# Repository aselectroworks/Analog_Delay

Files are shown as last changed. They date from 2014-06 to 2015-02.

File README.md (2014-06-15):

Analog_Delay
============

Multiple function BBD Analog Delay assisted by Digital Domain. 

### Features
* Max. 1000 ms delay by 4 BBDs
* Stereo In/Out
* Monaural In/Stereo Out(ping-pong or fx+dryout)
* Tap tempo function assisted by digital domain 
* Delay effect remain or bypass selectable when fx function off
* LCD display

### Design Tools
* [KiCAD](http://www.kicad-pcb.org/)
* [atmel studio 6](http://www.atmel.com/tools/ATMELSTUDIO.aspx)

### Download
You can download this project in either [zip](https://github.com/aselectroworks/Analog_Delay/zipball/master) or [tar](https://github.com/aselectroworks/Analog_Delay/tarball/master) formats. 
You can also clone this project with [git](http://git-scm.com/) by runninng: 
```
$ git clone git://github.com/aselectroworks/Analog_Delay
```

### License
GPL v3

### Contact
atsushi.sasaki@aselectroworks.com

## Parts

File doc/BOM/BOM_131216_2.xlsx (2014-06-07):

ID | Parts Ref. Number | Package | pcs | Value | Toralance | Voltage | Type | Parts Name | Manufacturer | Smart-Prototyping Materials | Shop URL
1 | C631,C609,C635,C613,C628,C606,C213,C206,C218,C214,C321,C205,C212,C615,C616,C617,C620,C621,C622,C629,C636,C607,C230,C223,C301,C231,C224,C614,C314,C309,C308,C322,C644,C638,C641,C501,C502 | C0402 | 37 | 100n | ±10% | 16V | X7R | GRM155R71C104KA88D | - | Yes | -
2 | R620,R606,R221,R206 | R0402 | 4 | 47k | ±5% | - | - | - | - | Yes | -
3 | R602,R616,R225,R219,R204,R210 | R0603 | 6 | 3.3k | ±5% | - | - | - | - | Yes | -
4 | R611,R626,R229,R214 | R0603 | 4 | 1.5k | ±5% | - | - | - | - | Yes | -
5 | R603,R608,R622,R617 | R0603 | 4 | 2.7k | ±5% | - | - | - | - | Yes | -
6 | R612,R627 | R0603 | 2 | 1.2k | ±5% | - | - | - | - | Yes | -
7 | R609,R623 | R0603 | 2 | 2.2k | ±5% | - | - | - | - | Yes | -
8 | C610,C632,C209,C227 | C0603 | 4 | 22n | ±10% | 25V | X7R | GRM188R71E223KA01D | - | Yes | -
9 | C604,C626,C624,C602,C202,C627,C221,C220,C222,C203,C204,C605 | C0603 | 12 | 10n | ±10% | 25V | X7R | GRM188R71E103KA01D | - | Yes | -
10 | C611,C633,C210,C228 | C0603 | 4 | 33n | ±10% | 16V | X7R | GRM188R71C333KA01D | - | Yes | -
11 | U601,U606,U205,U204,U607,U602,U202,U201 | DMP8 | 8 | NJM4558M | - | - | - | NJM4558M | JRC | - | http://hongkong01.rs-online.com/web/p/operational-amplifiers/7405581/
12 | D401 | UMD2 | 1 | 1SS355VMTE-17 | - | - | - | 1SS355VMTE-17 | Rohm | - | http://www.digikey.hk/product-detail/en/1SS355VMTE-17/1SS355VMTE-17CT-ND/3443692
13 | U403 | DPAK | 1 | MC79M05CDTG | - | - | - | MC79M05CDTG | ON Semiconductor | - | http://www.digikey.hk/product-detail/en/MC79M05CDTG/MC79M05CDTGOS-ND/1481613
14 | U401 | TO-252-3 | 1 | NJM78M05DL1A | - | - | - | NJM78M05DL1A | JRC | - | http://hongkong02.rs-online.com/web/p/linear-voltage-regulators/7139543/?searchTerm=NJM78M05DL1A
15 | U402 | S8 | 1 | LTC1144CS8 | - | - | - | LTC1144CS8 | Linear Technology | - | http://www.digikey.hk/product-detail/en/LTC1144CS8%23PBF/LTC1144CS8%23PBF-ND/889942
16 | R224,R228,R218,R209,R203,R213 | R0603 | 6 | 3.9k | ±5% | - | - | - | - | Yes | -
17 | R215,R230 | R0603 | 2 | 1M | ±5% | - | - | - | - | Yes | -
18 | R621,R629,R615,R332,R316,R333,R601,R607,R614,R630,R222,R205,R207,R220,R334,R632 | R0603 | 16 | 47k | ±5% | - | - | - | - | Yes | -
19 | R619,R605 | R0603 | 2 | 6.8k | ±5% | - | - | - | - | Yes | -
20 | R402,R401 | R0603 | 2 | 0 | ±5% | - | - | - | - | Yes | -
21 | R604,R618 | R0603 | 2 | 1k | ±5% | - | - | - | - | Yes | -
22 | R613,R610,R624,R628 | R0603 | 4 | 820 | ±5% | - | - | - | - | Yes | -
23 | R625,R631 | R0603 | 2 | 33 | ±5% | - | - | - | - | Yes | -
24 | R226,R211 | R0603 | 2 | 5.1k | ±5% | - | - | - | - | Yes | -
25 | R217,R202,R201,R208,R223,R216,R232,R231 | R0603 | 8 | 5.6k | ±5% | - | - | - | - | Yes | -
26 | R212,R227 | R0603 | 2 | 4.7k | ±5% | - | - | - | - | Yes | -
27 | J401 | MJ-179SMT | 1 | MJ-179SMT | - | - | - | MJ-179SMT | - | - | http://sg.element14.com/multicomp/mj-179smt/chassis-socket-psu-smt-2mm-pin/dp/1737262
28 | C403,C404,C406,C401,C402,C407,C405,C216,C217,C619,C618,C639,C642,C637,C640 | C0805 | 15 | 10u | ±10% | 10V | X5R | GRM21BR61A106KE19L | - | Yes | -
29 | C208,C623,C226,C601 | C0603 | 4 | 15n | ±10% | 25V | X7R | GRM188R71E153KA01D | - | Yes | -
30 | C634,C612 | C0603 | 2 | 100n | ±10% | 16V | X7R | GRM188R71C104KA01D | - | Yes | -
31 | C630,C625,C603,C608 | C0603 | 4 | 3.3n | ±10% | 50V | X7R | GRM188R71H332KA01D | - | Yes | -
32 | C201,C219 | C0603 | 2 | 1.2n | ±10% | 50V | X7R | GRM188R71H122KA01D | - | Yes | -
33 | C304,C317,C207,C225,C646,C234,C233,C320,C307 | C0603 | 9 | 2.2u | ±10% | 6.3V | X5R | GRM188R60J225KE19D | - | Yes | -
34 | C229,C211 | C0603 | 2 | 82n | ±10% | 16V | X7R | GRM188R71C823KA01D | - | Yes | -
35 | J602,J601,J202,J201 | ACJS-MHDRM | 4 | ACJS-MHDRM | - | - | - | ACJS-MHDRM | Amphenol | - | http://hk.mouser.com/ProductDetail/Amphenol/ACJS-MHDRM/
36 | SW501,SW502 | 8Y10 | 2 | 8Y1021 | - | - | - | 8Y1021 | Fujisoku | - | http://hongkong01.rs-online.com/web/p/push-button-switches/0223430/?searchTerm=8Y1021
37 | C313,C311,C306,C324,C319,C310,C303,C323,C316,C312,C326,C325 | C0402 | 12 | 1u | ±10% | 10V | X5R | GRM155R61A105KE15D | - | Yes | -
38 | C318,C315,C302,C305 | C0402 | 4 | 10n | ±10% | 50V | X7R | GRM155R71H103KA88D | - | Yes | -
39 | C232,C215 | C0402 | 2 | 1n | ±10% | 50V | X7R | GRM155R71H102KA01D | - | Yes | -
40 | R328,R329,R312,R313 | R0402 | 4 | 100k | ±5% | - | - | - | - | Yes | -
41 | R304,R321,R322,R323,R320,R307,R306,R305 | R0402 | 8 | 0 | ±5% | - | - | - | - | Yes | -
42 | R325,R324,R308,R309 | R0402 | 4 | 12k | ±5% | - | - | - | - | Yes | -
43 | R318,R302,R303,R319 | R0402 | 4 | Don't Source | - | - | - | - | - | - | -
44 | R317,R301 | R0402 | 2 | 5.6k | ±5% | - | - | - | - | Yes | -
45 | R327,R330,R326,R331,R310,R314,R315,R311 | R0402 | 8 | 4.7k | ±5% | - | - | - | - | Yes | -
46 | U608 | RU-16 | 1 | AD5282BRUZ200 | - | - | - | AD5282BRUZ200 | Analog Devices | - | http://www.digikey.hk/product-detail/en/AD5282BRUZ200/AD5282BRUZ200-ND/936629
47 | R639,R633,R634 | R0402 | 3 | 10k | ±5% | - | - | - | - | Yes | -
48 | R636,R635,R637,R638,R501,R502,R640 | R0402 | 7 | 100 | ±5% | - | - | - | - | Yes | -
49 | X601 | DNP | 1 | Don't Source | - | - | - | - | - | - | -
50 | P601 | DNP | 1 | Don't Source | - | - | - | - | - | - | -
51 | C643,C645 | C0603 | 2 | 1u | ±10% | 10V | X5R | GRM188R61A105KA61D | - | Yes | -
52 | C647 | C0402 | 1 | 1n | ±10% | 50V | X7R | GRM155R71H102KA01D | - | Yes | -
53 | C649,C648 | C0402 | 2 | 22p | ±5% | 50V | C0G | GRM1555C1H220JZ01D | - | Yes | -
54 | IC601 | 20S2 | 1 | ATTINY861A-S | - | - | - | ATTINY861A-S | Atmel | - | http://www.digikey.hk/product-detail/en/ATTINY861A-SUR/ATTINY861A-SURCT-ND/2774370
55 | CON601 | 06FMN-BMTTN-A-TF | 1 | 06FMN-BMTTN-A-TF | - | - | - | 06FMN-BMTTN-A-TF | JST | - | http://www.digikey.hk/product-detail/en/06FMN-BMTTN-A-TF(LF)(SN)/455-1922-1-ND/1634946
56 | U604 | RU-24 | 1 | AD5263BRU200 | - | - | - | AD5263BRU200 | Analog Devices | - | http://www.digikey.hk/product-search/en?WT.z_header=search_go&lang=en&site=hk&formaction=on&x=0&y=0
57 | U203 | RM-10 | 1 | ADG621BRMZ | - | - | - | ADG621BRMZ | Analog Devices | - | http://www.digikey.hk/product-detail/en/ADG621BRMZ/ADG621BRMZ-ND/997745
58 | U605,U603,U310,U305 | RM-8 | 4 | ADG619BRMZ | - | - | - | ADG619BRMZ | Analog Devices | - | http://www.digikey.hk/product-detail/en/ADG619BRMZ/ADG619BRMZ-ND/820101
59 | U306,U307,U302,U301 | DNP | 4 | Don't Source | - | - | - | - | - | - | -
60 | U308,U309,U304,U303 | DNP | 4 | Don't Source | - | - | - | - | - | - | -

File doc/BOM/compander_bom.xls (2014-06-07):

Id | Designator | Package | Quantity | Designation | Supplier and ref
1 | D105,D104,D101,D102,D103 | UMD2 | 5 | 1SS355VMTE-17 | http://www.rohm.com/web/global/products/-/product/1SS355VM
2 | U101 | SOIC-16_WB | 1 | SA571DG | http://www.onsemi.jp/PowerSolutions/product.do?id=SA571
3 | P101,P102 | S6B-PH-K-S | 2 | OPEN | DON'T SOURCE
4 | RV101,RV102 | RV2 | 2 | OPEN | DON'T SOURCE
5 | R108,R102,R117,R101,R107 | r_1608 | 5 | 0 | 0603size(1.6mm x 0.8mm)
6 | R110,R109 | r_1608 | 2 | OPEN | DON'T SOURCE
7 | R105,R106,R103,R104 | r_1608 | 4 | 22k | 0603size(1.6mm x 0.8mm), tolerance: 5%, in your web shop
8 | R112,R114,R111,R113 | r_1608 | 4 | 10k | 0603size(1.6mm x 0.8mm), tolerance: 5%, in your web shop
9 | R116,R115 | r_1608 | 2 | 5.6k | 0603size(1.6mm x 0.8mm), tolerance: 5%, in your web shop
10 | C122,C115,C116 | c_2012 | 3 | GRM21BR61A106KE19L | 10uF±10% 10V X5R, in your web shop
11 | C104,C119,C101,C102,C117,C103,C105,C107,C109,C110,C108,C120,C118,C106 | c_1608 | 14 | GRM188R60J225KE19D | 2.2uF±10% 6.3V X5R, in your web shop
12 | C113,C114 | c_1608 | 2 | GRM1885C1H201JA01D | 200pF±5% 50V C0G, in your web shop
13 | C121 | c_1608 | 1 | GRM188R71C104KA01D | 100nF±10% 16V X7R, in your web shop
14 | C111,C112 | c_1608 | 2 | GRM188R71C224KA01D | 220nF±10% 16V X7R, in your web shop

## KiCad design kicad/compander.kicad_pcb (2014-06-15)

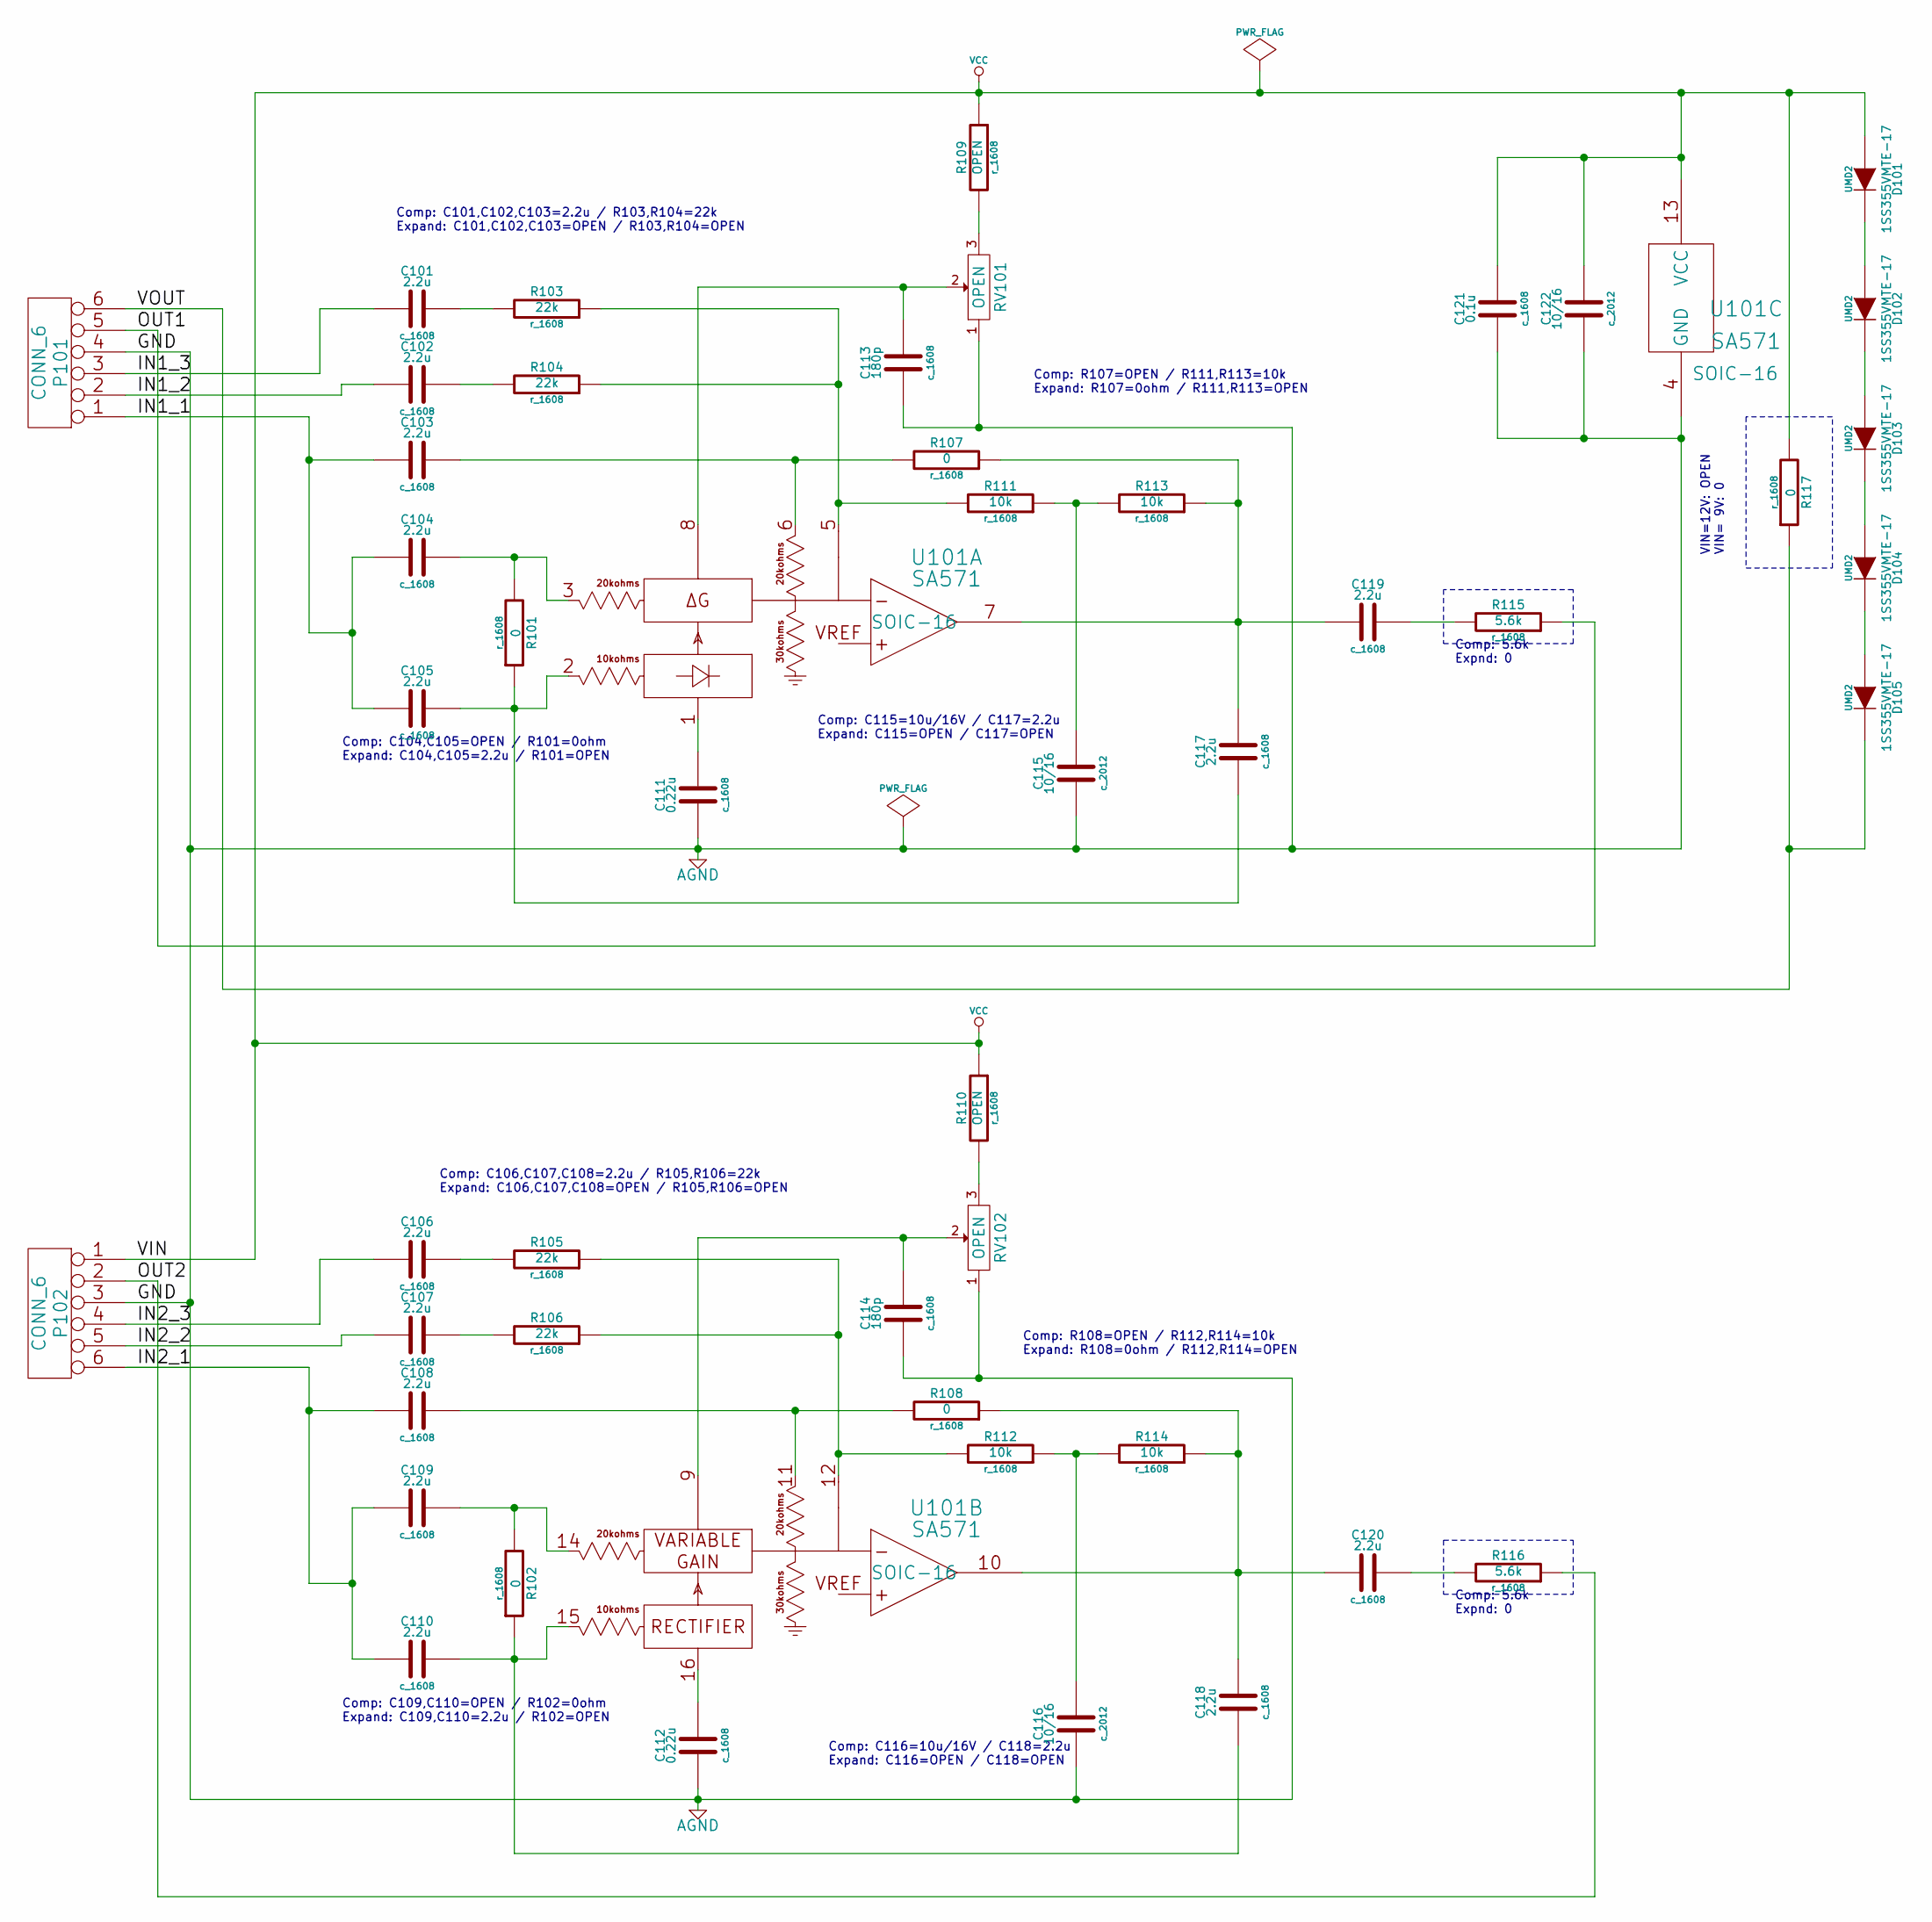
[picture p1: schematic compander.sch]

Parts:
C101, C102, C103, C104, C105, C106, C107, C108, C109, C110, C117, C118, C119, C120: 2.2u; c_1608
C111, C112: 0.22u; c_1608
C113, C114: 180p; c_1608
C115, C116, C122: 10/16; c_2012
C121: 0.1u; c_1608
D101, D102, D103, D104, D105: 1SS355VMTE-17; UMD2
P101, P102: CONN_6
R101, R102, R107, R108, R117: 0; r_1608
R103, R104, R105, R106: 22k; r_1608
R109, R110: OPEN; r_1608
R111, R112, R113, R114: 10k; r_1608
R115, R116: 5.6k; r_1608
RV101, RV102: OPEN
U101: SA571; SOIC-16

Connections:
/IN1_1: C103.1, C104.1, C105.1, P101.1
/IN1_2: C102.1, P101.2
/IN1_3: C101.1, P101.3
/IN2_1: C108.1, C109.1, C110.1, P102.6
/IN2_2: C107.1, P102.5
/IN2_3: C106.1, P102.4
/OUT1: P101.5, R115.1
/OUT2: P102.2, R116.1
/VOUT: D105.2 (K), P101.6, R117.1
AGND: C111.1, C112.1, C113.1, C114.1, C115.1, C116.1, C121.1, C122.1, P101.4, P102.3, RV101.1, RV102.1, U101.4 (GND)
unnamed: C114.2, RV102.2, U101.9 (THD_TRIM_2)
unnamed: R110.2, RV102.3
unnamed: C104.2, R101.2, U101.3 (DG_CELL_IN_1)
unnamed: R105.1, R106.1, R112.2, U101.12 (INV._IN_2)
unnamed: C107.2, R106.2
unnamed: C106.2, R105.2
unnamed: C120.2, R116.2
unnamed: C115.2, R111.1, R113.2
unnamed: R103.1, R104.1, R111.2, U101.5 (INV._IN_1)
unnamed: C102.2, R104.2
unnamed: C101.2, R103.2
unnamed: C119.2, R115.2
unnamed: C105.2, C117.1, R101.1, U101.2 (RECT_IN_1)
unnamed: C116.2, R112.1, R114.2
unnamed: C111.2, U101.1 (RECT_CAP_1)
unnamed: C103.2, R107.2, U101.6 (RES._R3_1)
unnamed: C117.2, C119.1, R107.1, R113.1, U101.7 (OUTPUT_1)
unnamed: D101.2 (K), D102.1 (A)
unnamed: D104.2 (K), D105.1 (A)
unnamed: D103.2 (K), D104.1 (A)
unnamed: D102.2 (K), D103.1 (A)
unnamed: C112.2, U101.16 (RECT_CAP_2)
unnamed: C108.2, R108.2, U101.11 (RES._R3_2)
unnamed: C118.2, C120.1, R108.1, R114.1, U101.10 (OUTPUT_2)
unnamed: C110.2, C118.1, R102.1, U101.15 (RECT_IN_2)
unnamed: C109.2, R102.2, U101.14 (DG_CELL_IN_2)
unnamed: C113.2, RV101.2, U101.8 (THD_TRIM_1)
unnamed: R109.2, RV101.3
VCC: C121.2, C122.2, D101.1 (A), P102.1, R109.1, R110.1, R117.2, U101.13 (VCC)

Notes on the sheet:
Comp: 5.6k Expnd: 0
VIN=12V: OPEN VIN= 9V: 0
Comp: C104,C105=OPEN / R101=0ohm Expand: C104,C105=2.2u / R101=OPEN
Comp: C109,C110=OPEN / R102=0ohm Expand: C109,C110=2.2u / R102=OPEN
Comp: C106,C107,C108=2.2u / R105,R106=22k Expand: C106,C107,C108=OPEN / R105,R106=OPEN
Comp: C101,C102,C103=2.2u / R103,R104=22k Expand: C101,C102,C103=OPEN / R103,R104=OPEN
Comp: R107=OPEN / R111,R113=10k Expand: R107=0ohm / R111,R113=OPEN
Comp: R108=OPEN / R112,R114=10k Expand: R108=0ohm / R112,R114=OPEN
Comp: C116=10u/16V / C118=2.2u Expand: C116=OPEN / C118=OPEN
Comp: C115=10u/16V / C117=2.2u Expand: C115=OPEN / C117=OPEN

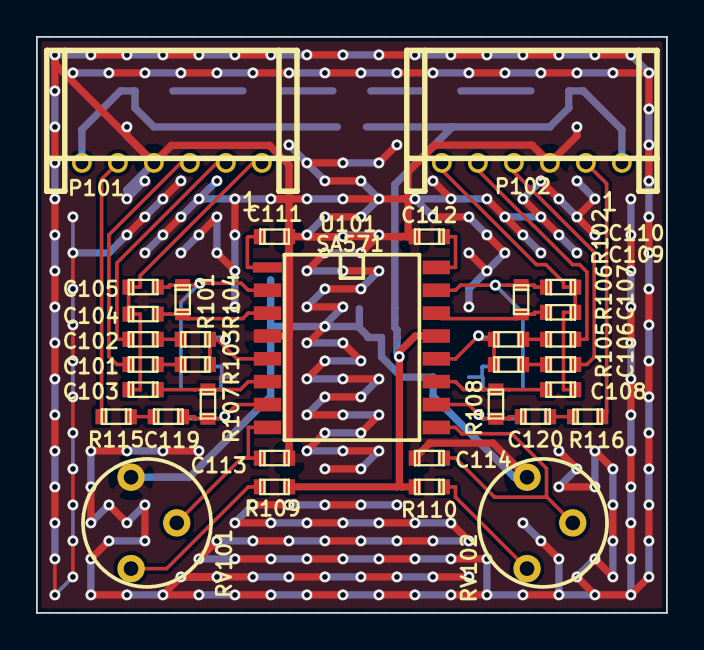
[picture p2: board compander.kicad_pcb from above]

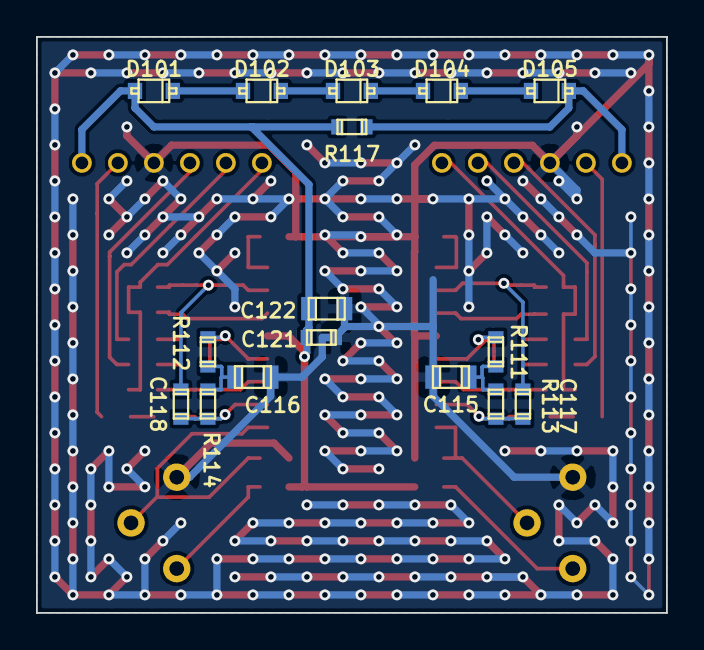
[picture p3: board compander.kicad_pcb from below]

Board: 2 copper layers, 35.0 x 32.0 mm, 49 parts (16 on the bottom side), 39 nets.

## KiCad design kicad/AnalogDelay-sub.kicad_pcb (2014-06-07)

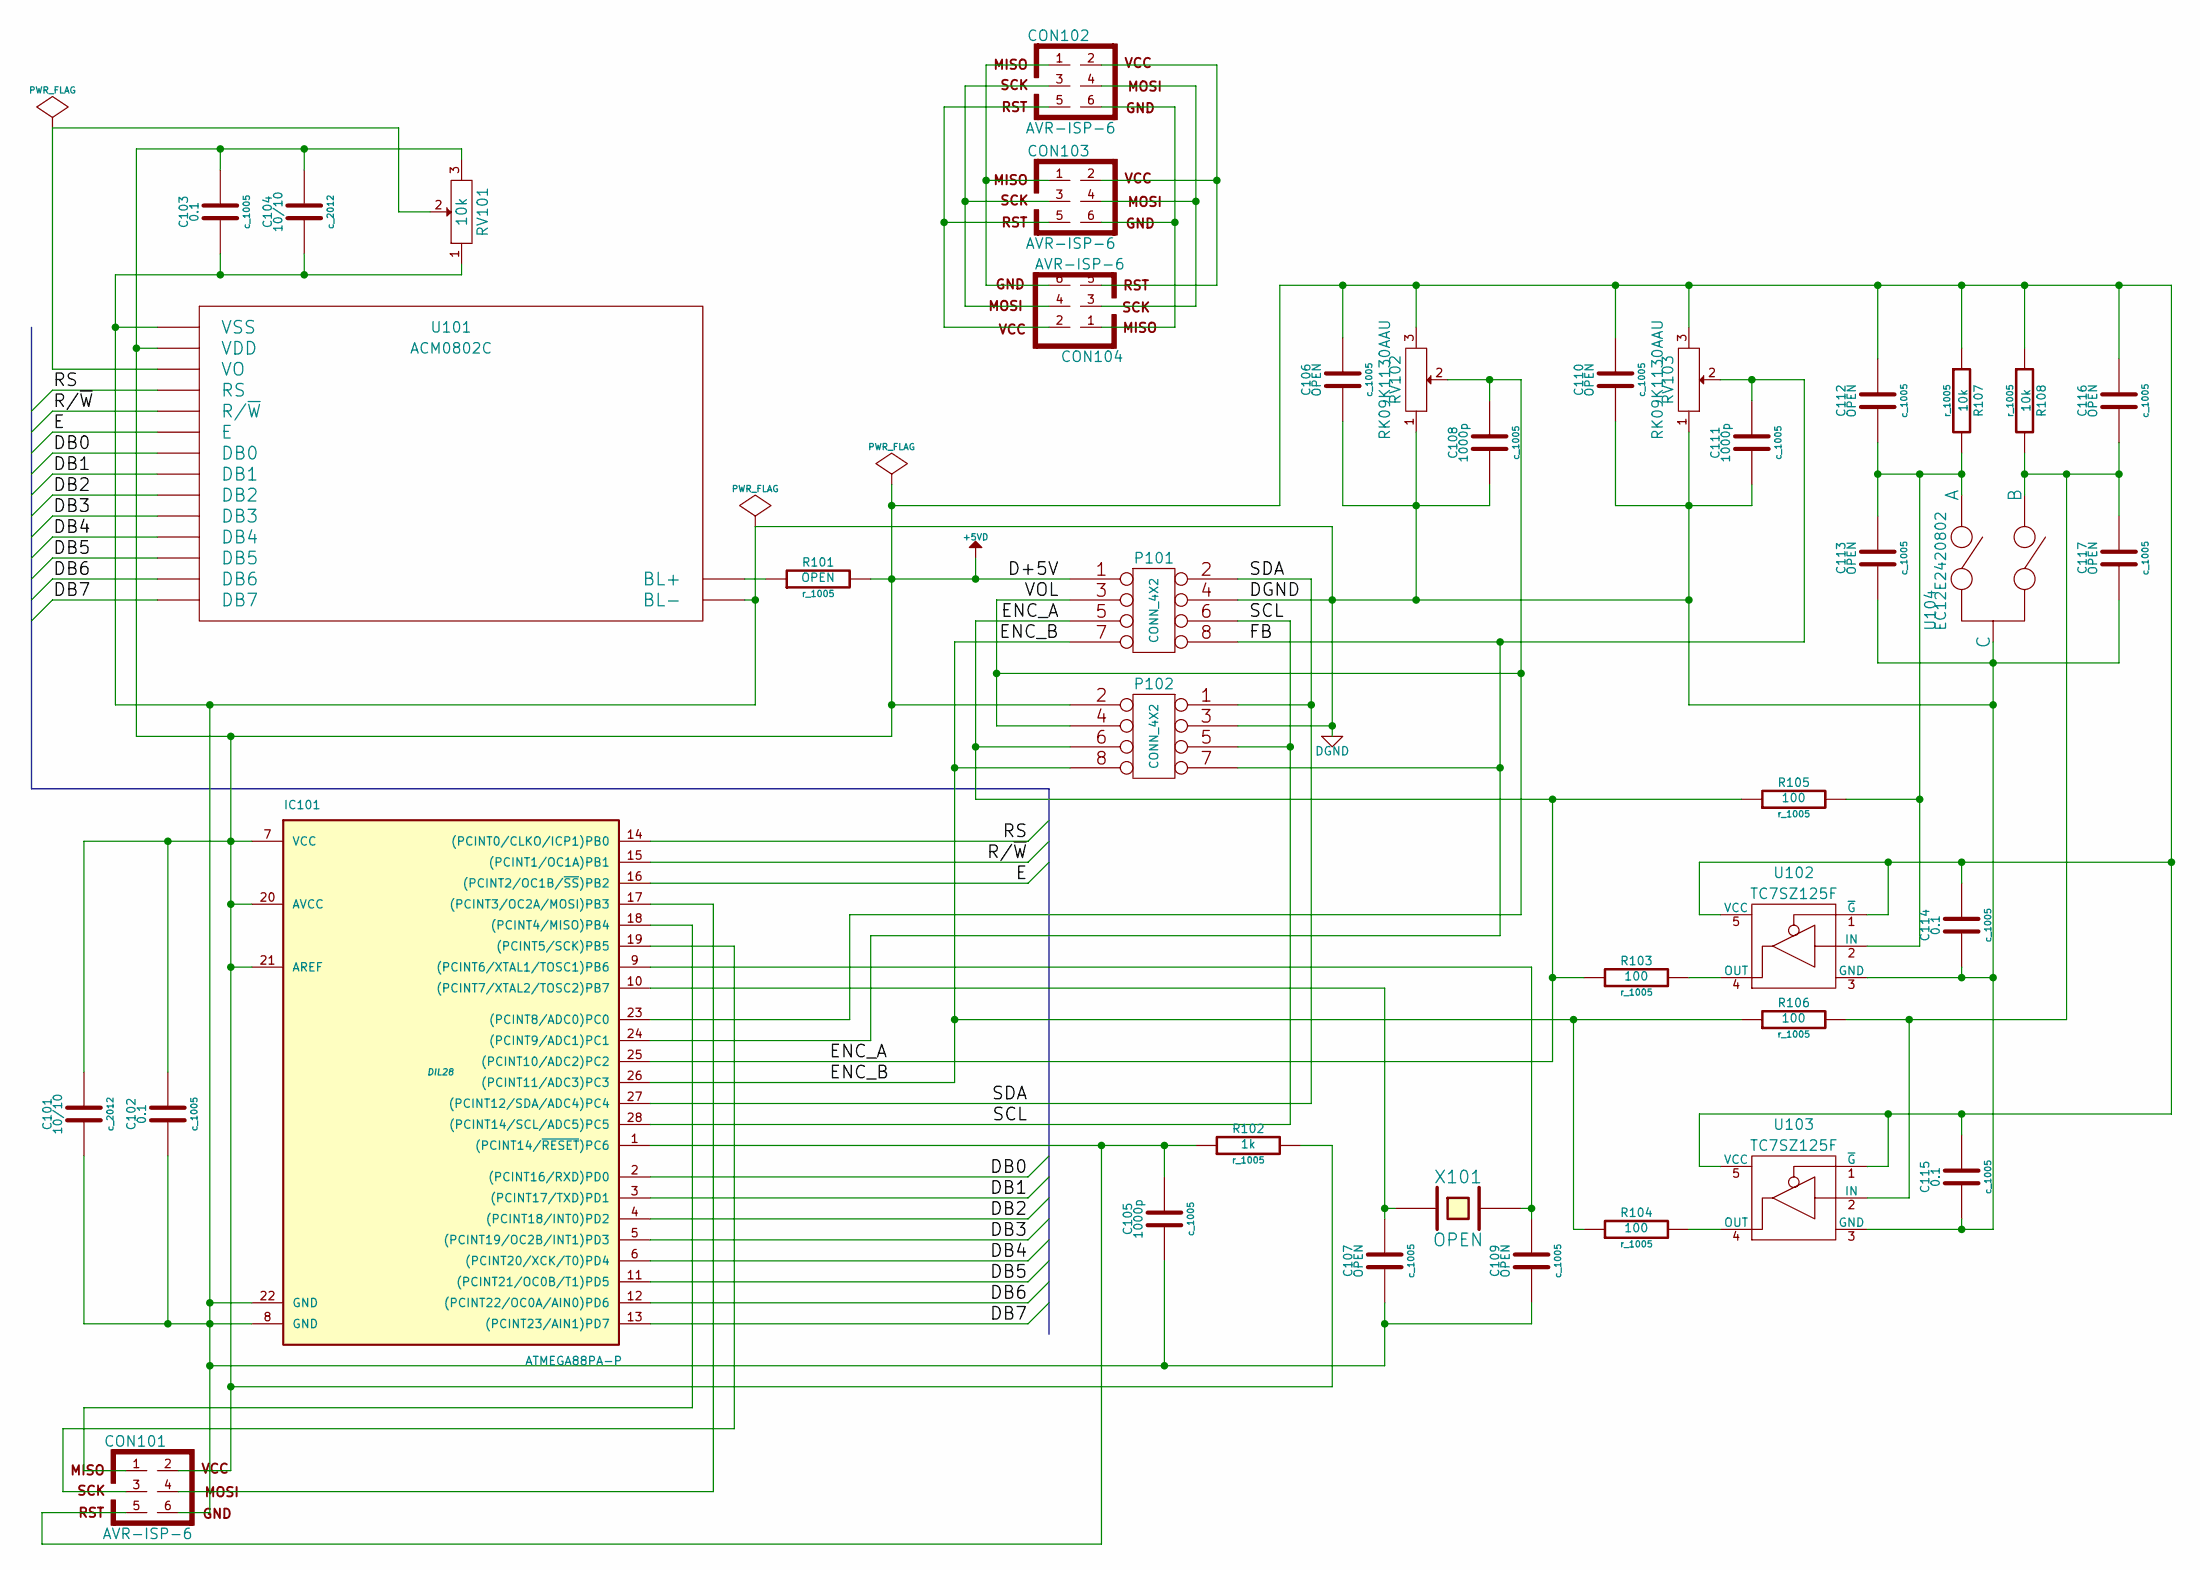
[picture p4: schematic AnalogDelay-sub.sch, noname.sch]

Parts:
C101, C104: 10/10; c_2012
C102, C103, C114, C115: 0.1; c_1005
C105, C108, C111: 1000p; c_1005
C106, C107, C109, C110, C112, C113, C116, C117: OPEN; c_1005
CON101, CON102, CON103, CON104: AVR-ISP-6
IC101: ATMEGA88PA-P; DIL28
P101, P102: CONN_4X2
R101: OPEN; r_1005
R102: 1k; r_1005
R103, R104, R105, R106: 100; r_1005
R107, R108: 10k; r_1005
RV101: 10k
RV102, RV103: RK09K1130AAU
U101: ACM0802C
U102, U103: TC7SZ125F; SC74-A
U104: EC12E2420802; EC12E-BUSHING-20
X101: OPEN

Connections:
+5VD: C101.2, C102.2, C103.2, C104.2, C106.2, C110.2, C112.2, C114.2, C115.2, C116.2, CON101.2, IC101.7 (VCC), IC101.20 (AVCC), IC101.21 (AREF), P101.1, P102.2, R101.2, R102.2, R107.1, R108.1, RV101.3, RV102.3, RV103.3, U101.2 (VDD), U102.1 (~G), U102.5 (VCC), U103.1 (~G), U103.5 (VCC)
/DB0: IC101.2 ((PCINT16/RXD)PD0), U101.7 (DB0)
/DB1: IC101.3 ((PCINT17/TXD)PD1), U101.8 (DB1)
/DB2: IC101.4 ((PCINT18/INT0)PD2), U101.9 (DB2)
/DB3: IC101.5 ((PCINT19/OC2B/INT1)PD3), U101.10 (DB3)
/DB4: IC101.6 ((PCINT20/XCK/T0)PD4), U101.11 (DB4)
/DB5: IC101.11 ((PCINT21/OC0B/T1)PD5), U101.12 (DB5)
/DB6: IC101.12 ((PCINT22/OC0A/AIN0)PD6), U101.13 (DB6)
/DB7: IC101.13 ((PCINT23/AIN1)PD7), U101.14 (DB7)
/E: IC101.16 ((PCINT2/OC1B/~SS~)PB2), U101.6 (E)
/ENC_A: IC101.25 ((PCINT10/ADC2)PC2), P101.5, P102.6, R103.1, R105.1
/ENC_B: IC101.26 ((PCINT11/ADC3)PC3), P101.7, P102.8, R104.1, R106.1
/FB: C111.2, IC101.24 ((PCINT9/ADC1)PC1), P101.8, P102.7, RV103.2
/R/~W: IC101.15 ((PCINT1/OC1A)PB1), U101.5 (R/~W)
/RS: IC101.14 ((PCINT0/CLKO/ICP1)PB0), U101.4 (RS)
/SCL: IC101.28 ((PCINT14/SCL/ADC5)PC5), P101.6, P102.5
/SDA: IC101.27 ((PCINT12/SDA/ADC4)PC4), P101.2, P102.1
/VOL: C108.2, IC101.23 ((PCINT8/ADC0)PC0), P101.3, P102.4, RV102.2
DGND: C101.1, C102.1, C103.1, C104.1, C105.1, C106.1, C107.1, C108.1, C109.1, C110.1, C111.1, C113.1, C114.1, C115.1, C117.1, CON101.6, IC101.8 (GND), IC101.22 (GND), P101.4, P102.3, RV101.1, RV102.1, RV103.1, U101.1 (VSS), U101.16 (BL-), U102.3 (GND), U103.3 (GND), U104.3 (C)
unnamed: CON101.1, IC101.18 ((PCINT4/MISO)PB4)
unnamed: CON101.4, IC101.17 ((PCINT3/OC2A/MOSI)PB3)
unnamed: CON101.3, IC101.19 ((PCINT5/SCK)PB5)
unnamed: C109.2, IC101.9 ((PCINT6/XTAL1/TOSC1)PB6), X101.2
unnamed: C107.2, IC101.10 ((PCINT7/XTAL2/TOSC2)PB7), X101.1
unnamed: CON102.3, CON103.3, CON104.4
unnamed: CON102.2, CON103.2, CON104.5
unnamed: CON102.1, CON103.1, CON104.6
unnamed: CON102.5, CON103.5, CON104.2
unnamed: CON102.6, CON103.6, CON104.1
unnamed: CON102.4, CON103.4, CON104.3
unnamed: C105.2, CON101.5, IC101.1 ((PCINT14/~RESET~)PC6), R102.1
unnamed: RV101.2, U101.3 (VO)
unnamed: R101.1, U101.15 (BL+)
unnamed: R104.2, U103.4 (OUT)
unnamed: R103.2, U102.4 (OUT)
unnamed: C112.1, C113.2, R105.2, R107.2, U102.2 (IN), U104.1 (A)
unnamed: C116.1, C117.2, R106.2, R108.2, U103.2 (IN), U104.2 (B)

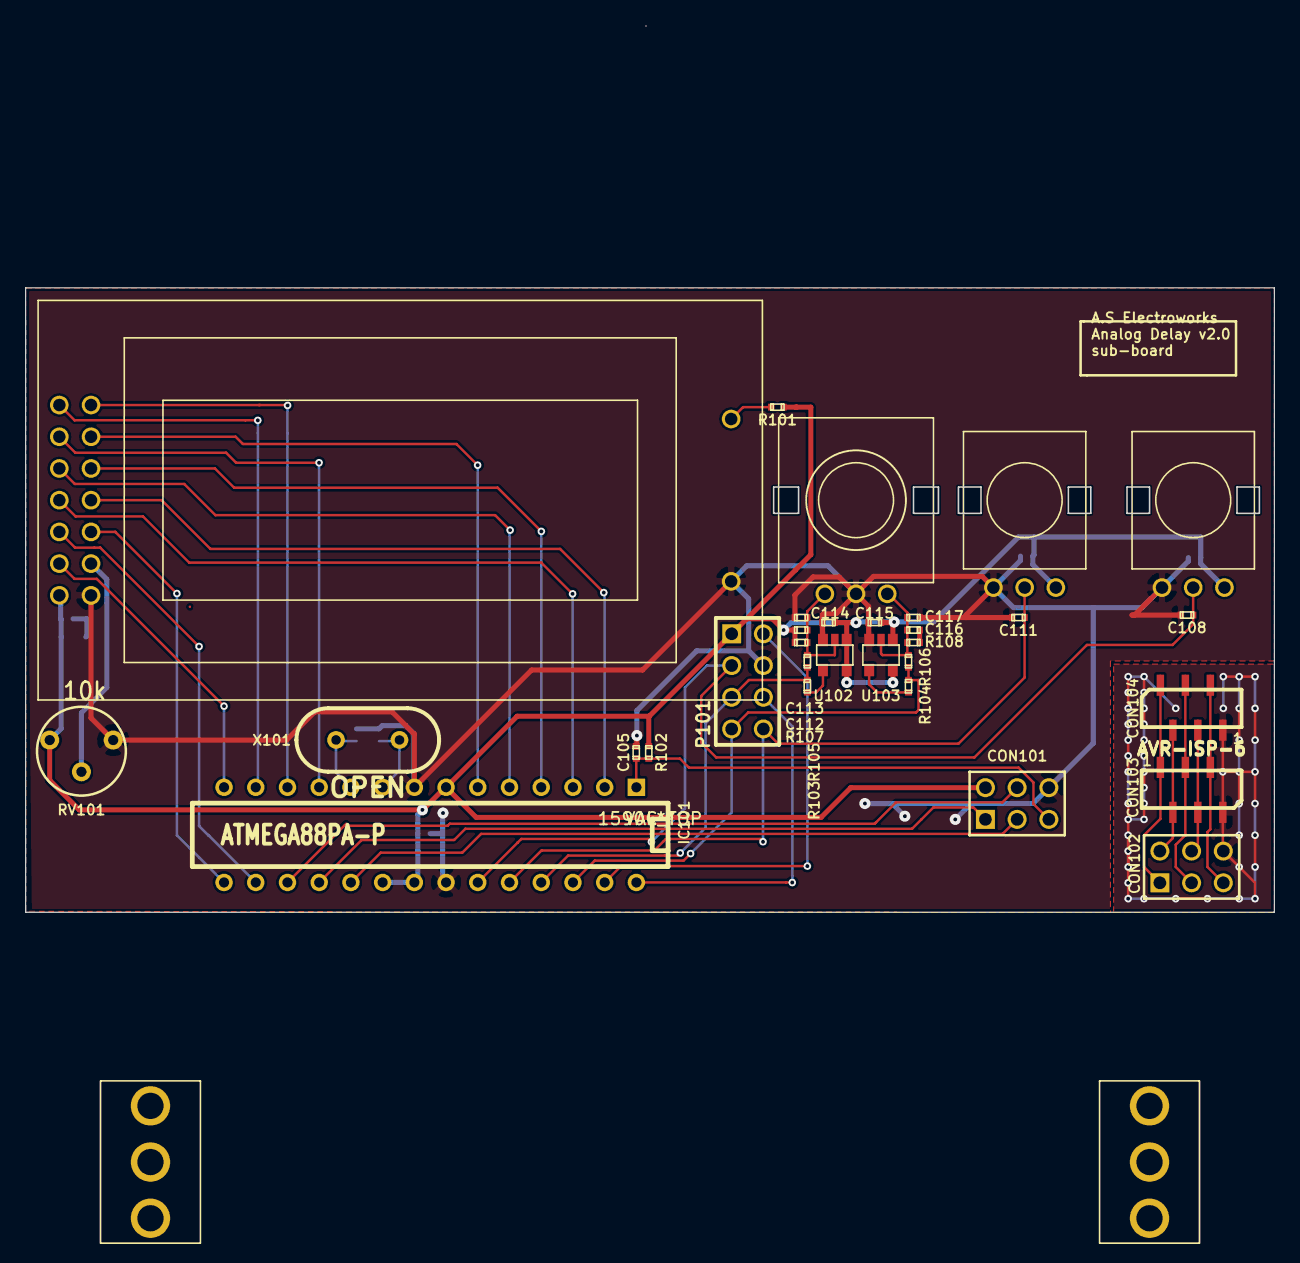
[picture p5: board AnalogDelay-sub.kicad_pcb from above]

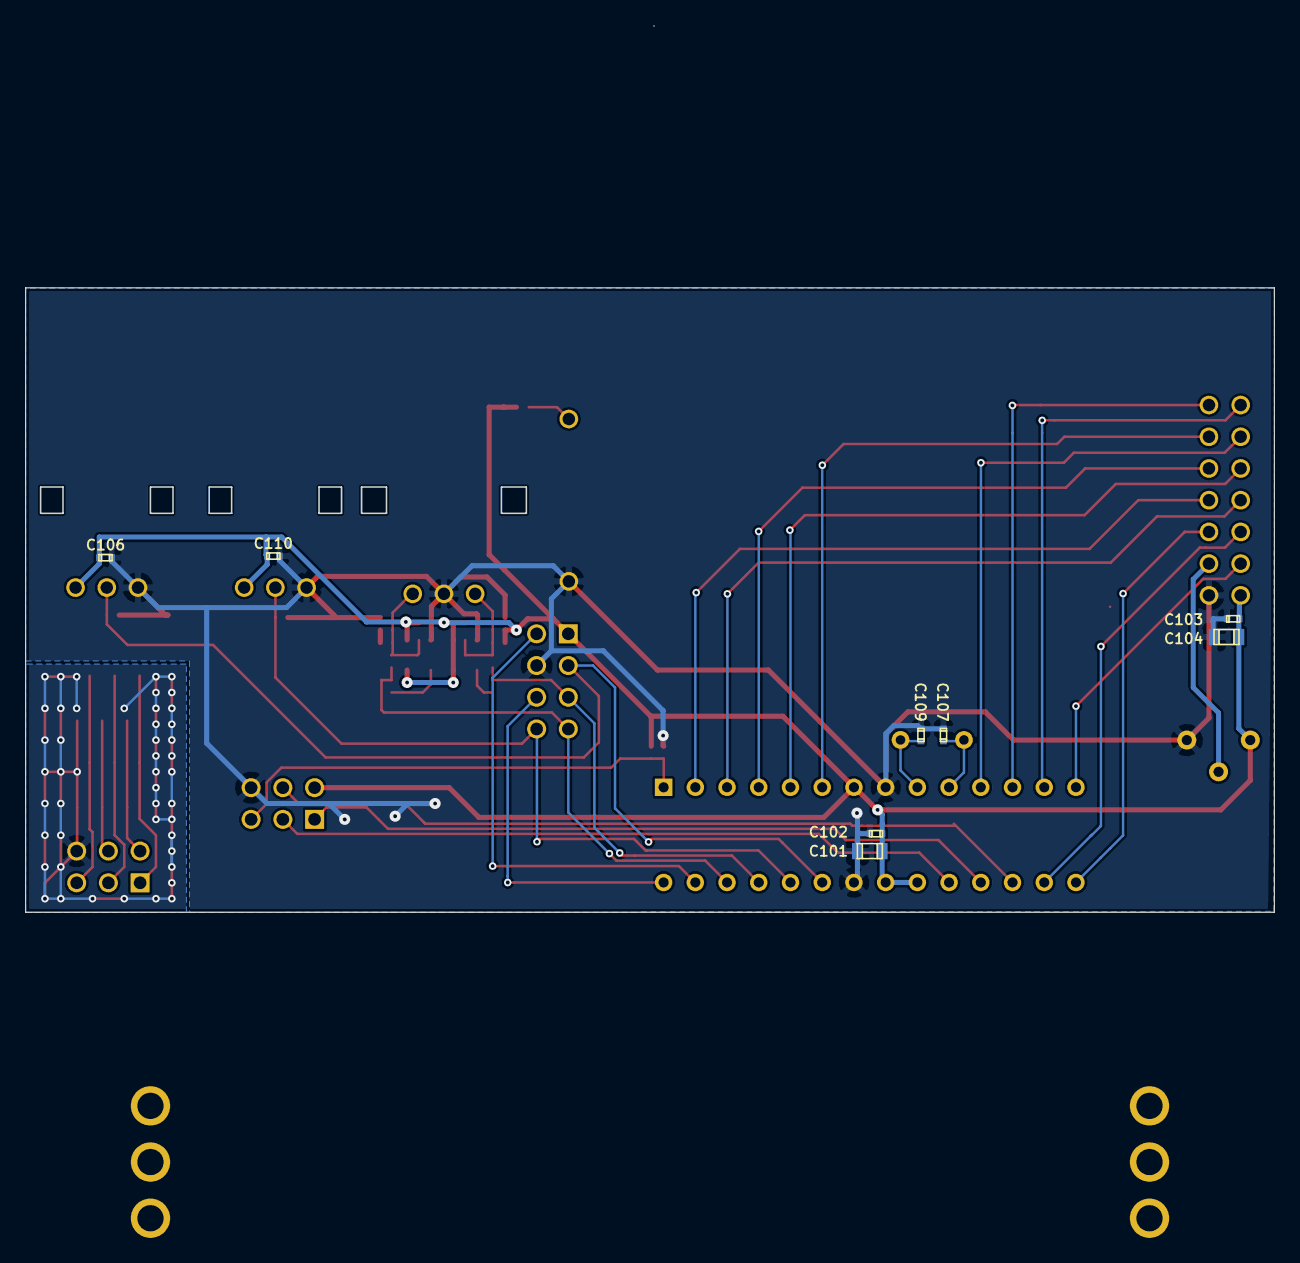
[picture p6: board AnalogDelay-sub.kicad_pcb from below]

Board: 2 copper layers, 100.0 x 50.0 mm, 43 parts (8 on the bottom side), 37 nets.

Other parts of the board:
1590C_SIDE: VAL**; 1590C_SIDE
1590C_TOP: VAL**; 1590C_TOP
SW***: 8Y10XX; 8Y10
SW***#2: 8Y10XX; 8Y10

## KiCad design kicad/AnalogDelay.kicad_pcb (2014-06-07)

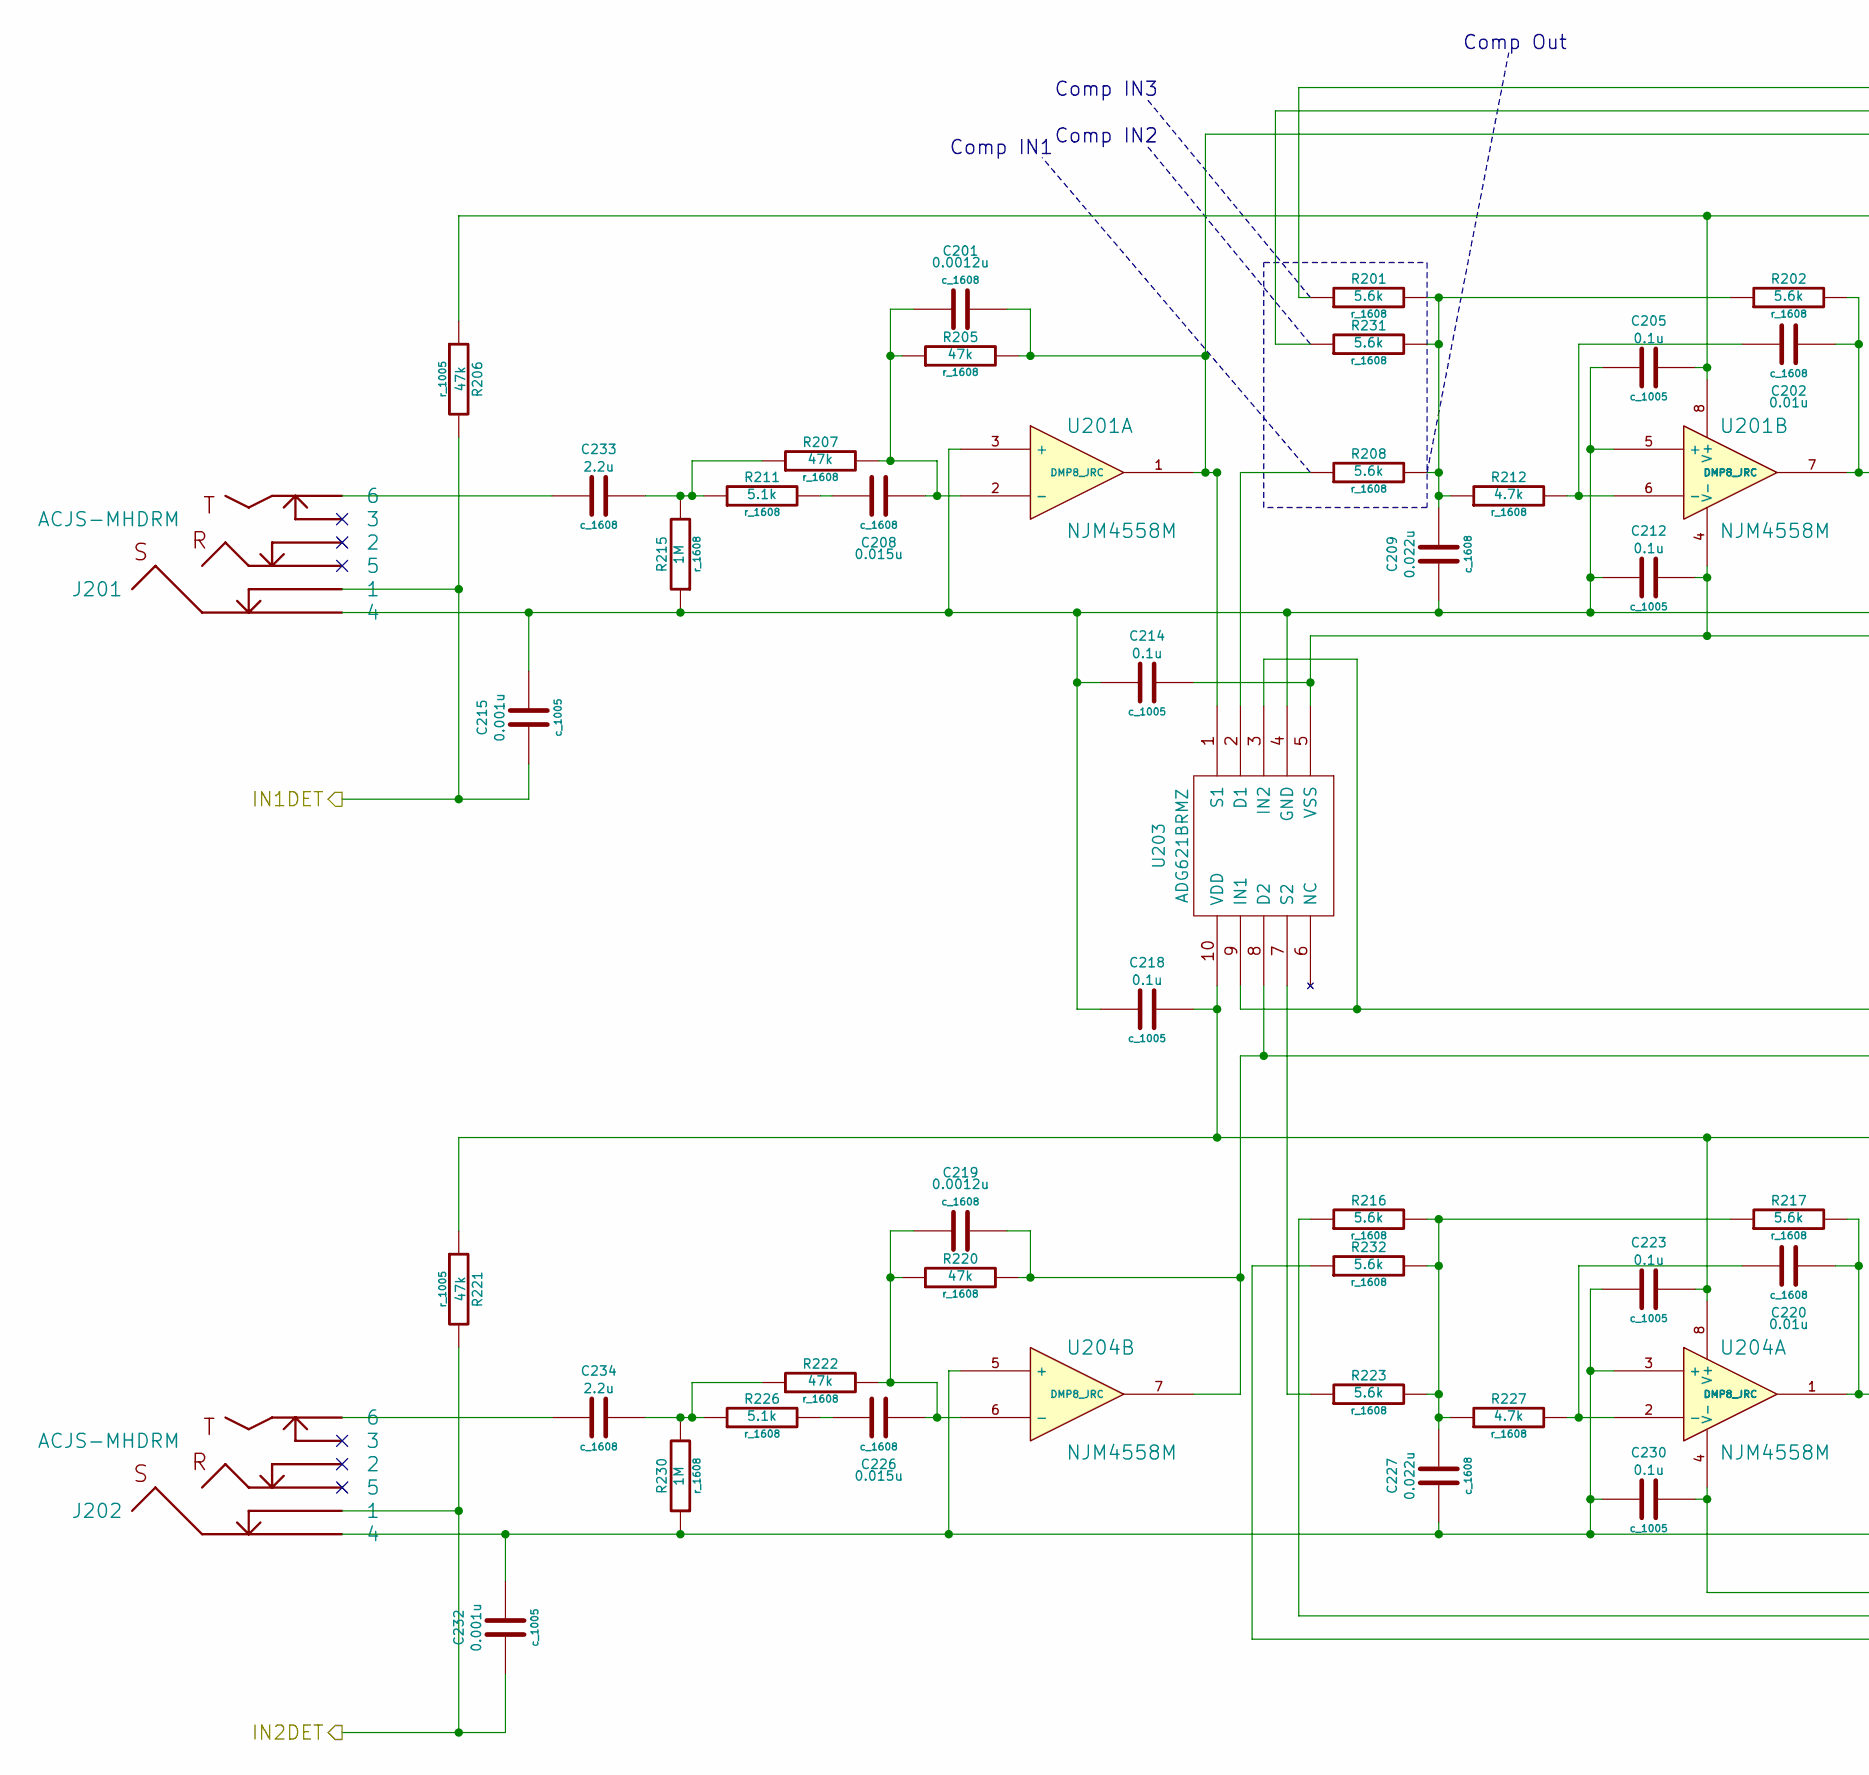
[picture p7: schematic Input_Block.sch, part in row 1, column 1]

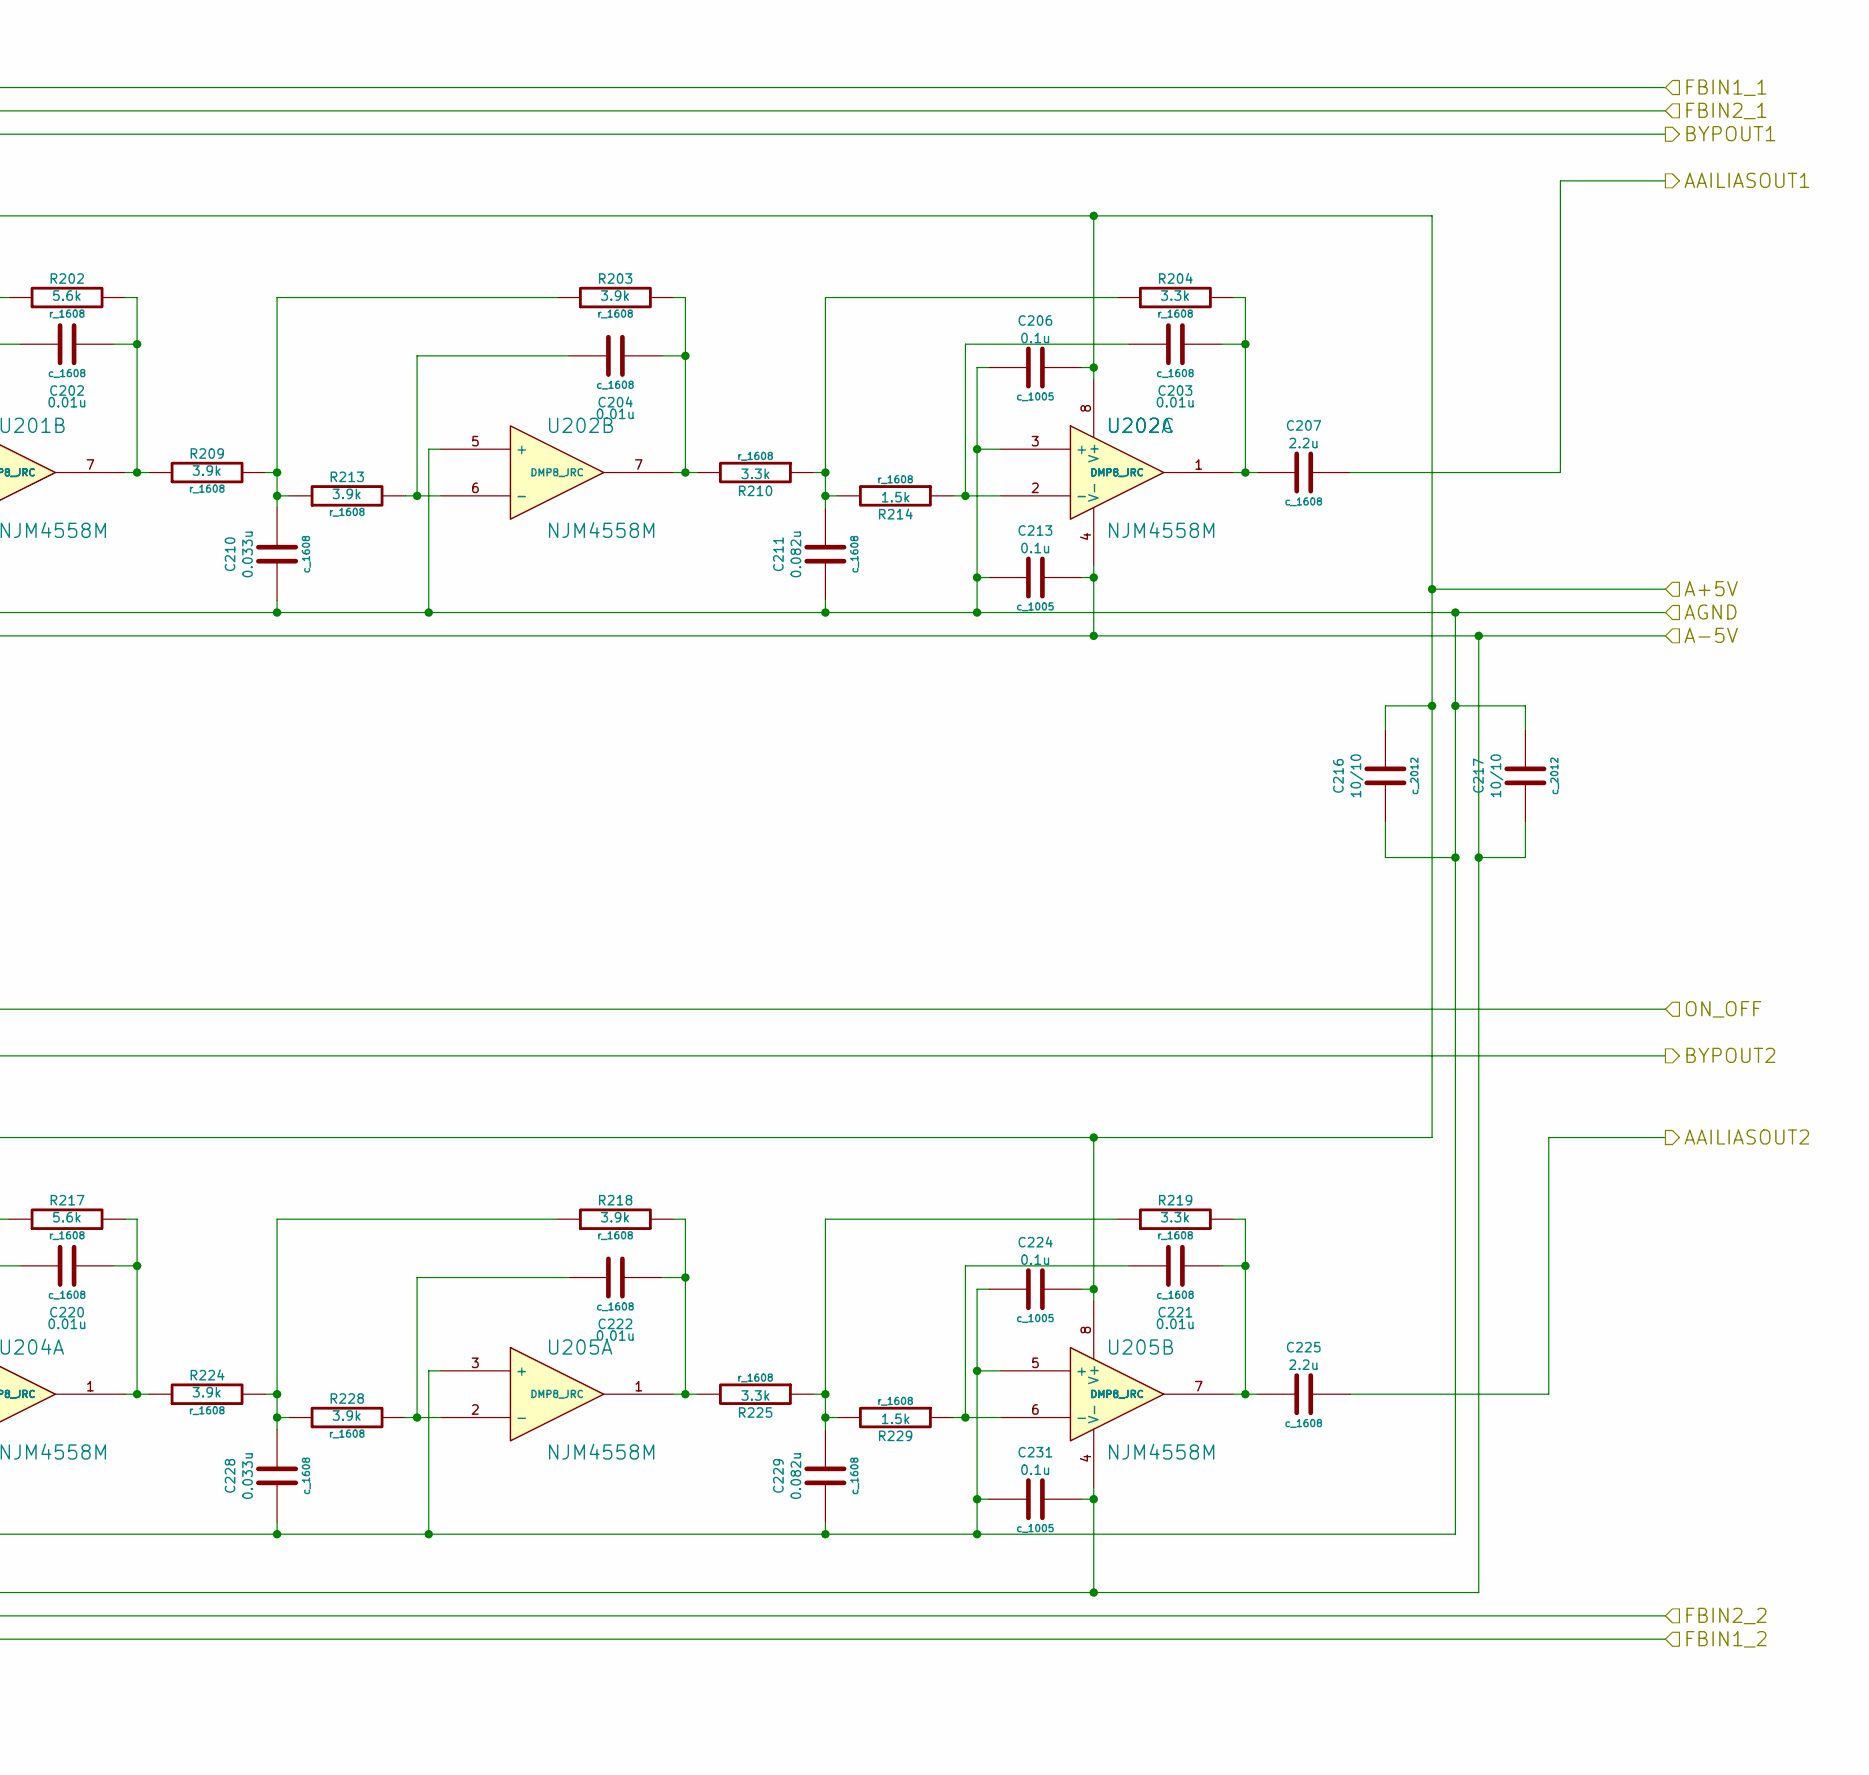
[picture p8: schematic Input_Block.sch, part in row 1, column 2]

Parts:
C201, C219: 0.0012u; c_1608
C202, C203, C204, C220, C221, C222: 0.01u; c_1608
C205, C206, C212, C213, C214, C218, C223, C224, C230, C231: 0.1u; c_1005
C207, C225, C233, C234: 2.2u; c_1608
C208, C226: 0.015u; c_1608
C209, C227: 0.022u; c_1608
C210, C228: 0.033u; c_1608
C211, C229: 0.082u; c_1608
C215, C232: 0.001u; c_1005
C216, C217: 10/10; c_2012
J201, J202: ACJS-MHDRM
R201, R202, R208, R216, R217, R223, R231, R232: 5.6k; r_1608
R203, R209, R213, R218, R224, R228: 3.9k; r_1608
R204, R210, R219, R225: 3.3k; r_1608
R205, R207, R220, R222: 47k; r_1608
R206, R221: 47k; r_1005
R211, R226: 5.1k; r_1608
R212, R227: 4.7k; r_1608
R214, R229: 1.5k; r_1608
R215, R230: 1M; r_1608
U201, U202, U204, U205: NJM4558M; DMP8_JRC
U203: ADG621BRMZ; RM-10

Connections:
+5VA: C205.2, C206.2, C216.2, C218.2, C223.2, C224.2, R206.1, R221.1, U201.8 (V+), U202.8 (V+), U203.10 (VDD), U204.8 (V+), U205.8 (V+); also elsewhere on the board
-5VA: C212.2, C213.2, C214.2, C217.1, C230.2, C231.2, U201.4 (V-), U202.4 (V-), U203.5 (VSS), U204.4 (V-), U205.4 (V-); also elsewhere on the board
/Clock Cancel Filter/Output Block/BYP1IN: C201.1, R205.2, U201.1, U203.1 (S1); also elsewhere on the board
/Clock Cancel Filter/Output Block/BYPIN2: C219.1, R220.2, U203.8 (D2), U204.7; also elsewhere on the board
/Connect Block/ON_OFF: U203.3 (IN2), U203.9 (IN1); also elsewhere on the board
/Input/Anti Alias Filter Block/AAILIASOUT1: C207.2; also elsewhere on the board
/Input/Anti Alias Filter Block/AAILIASOUT2: C225.2; also elsewhere on the board
/Input/Anti Alias Filter Block/FBIN1_1: R201.1; also elsewhere on the board
/Input/Anti Alias Filter Block/FBIN1_2: R232.1; also elsewhere on the board
/Input/Anti Alias Filter Block/FBIN2_1: R231.1; also elsewhere on the board
/Input/Anti Alias Filter Block/FBIN2_2: R216.1; also elsewhere on the board
/Input/Anti Alias Filter Block/IN1DET: C215.1, J201.1, R206.2; also elsewhere on the board
/Input/Anti Alias Filter Block/IN2DET: C232.1, J202.1, R221.2; also elsewhere on the board
AGND: C205.1, C206.1, C209.1, C210.1, C211.1, C212.1, C213.1, C214.1, C215.2, C216.1, C217.2, C218.1, C223.1, C224.1, C227.1, C228.1, C229.1, C230.1, C231.1, C232.2, J201.4, J202.4, R215.1, R230.1, U201.3 (+), U201.5 (+), U202.3 (+), U202.5 (+), U203.4 (GND), U204.3 (+), U204.5 (+), U205.3 (+), U205.5 (+); also elsewhere on the board
unnamed: C220.2, R217.2, R224.1, U204.1
unnamed: C228.2, R218.1, R224.2, R228.1
unnamed: C221.1, R229.1, U205.6 (-)
unnamed: C220.1, R227.2, U204.2 (-)
unnamed: C229.2, R219.1, R225.1, R229.2
unnamed: C222.2, R218.2, R225.2, U205.1
unnamed: C222.1, R228.2, U205.2 (-)
unnamed: C211.2, R204.1, R210.1, R214.2
unnamed: C203.1, R214.1, U202.2 (-)
unnamed: C204.2, R203.2, R210.2, U202.7
unnamed: C226.1, R226.2
unnamed: C219.2, C226.2, R220.1, R222.2, U204.6 (-)
unnamed: C203.2, C207.1, R204.2, U202.1
unnamed: R208.1, U203.2 (D1)
unnamed: R223.1, U203.7 (S2)
unnamed: C227.2, R216.2, R217.1, R223.2, R227.1, R232.2
unnamed: C233.1, J201.6
unnamed: C234.1, J202.6
unnamed: C221.2, C225.1, R219.2, U205.7
unnamed: C210.2, R203.1, R209.2, R213.1
unnamed: C202.2, R202.2, R209.1, U201.7
unnamed: C209.2, R201.2, R202.1, R208.2, R212.1, R231.2
unnamed: C201.2, C208.2, R205.1, R207.2, U201.2 (-)
unnamed: C233.2, R207.1, R211.1, R215.2
unnamed: C208.1, R211.2
unnamed: C204.1, R213.2, U202.6 (-)
unnamed: C202.1, R212.2, U201.6 (-)
unnamed: C234.2, R222.1, R226.1, R230.2

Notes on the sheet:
Comp IN1
Comp IN2
Comp IN3
Comp Out

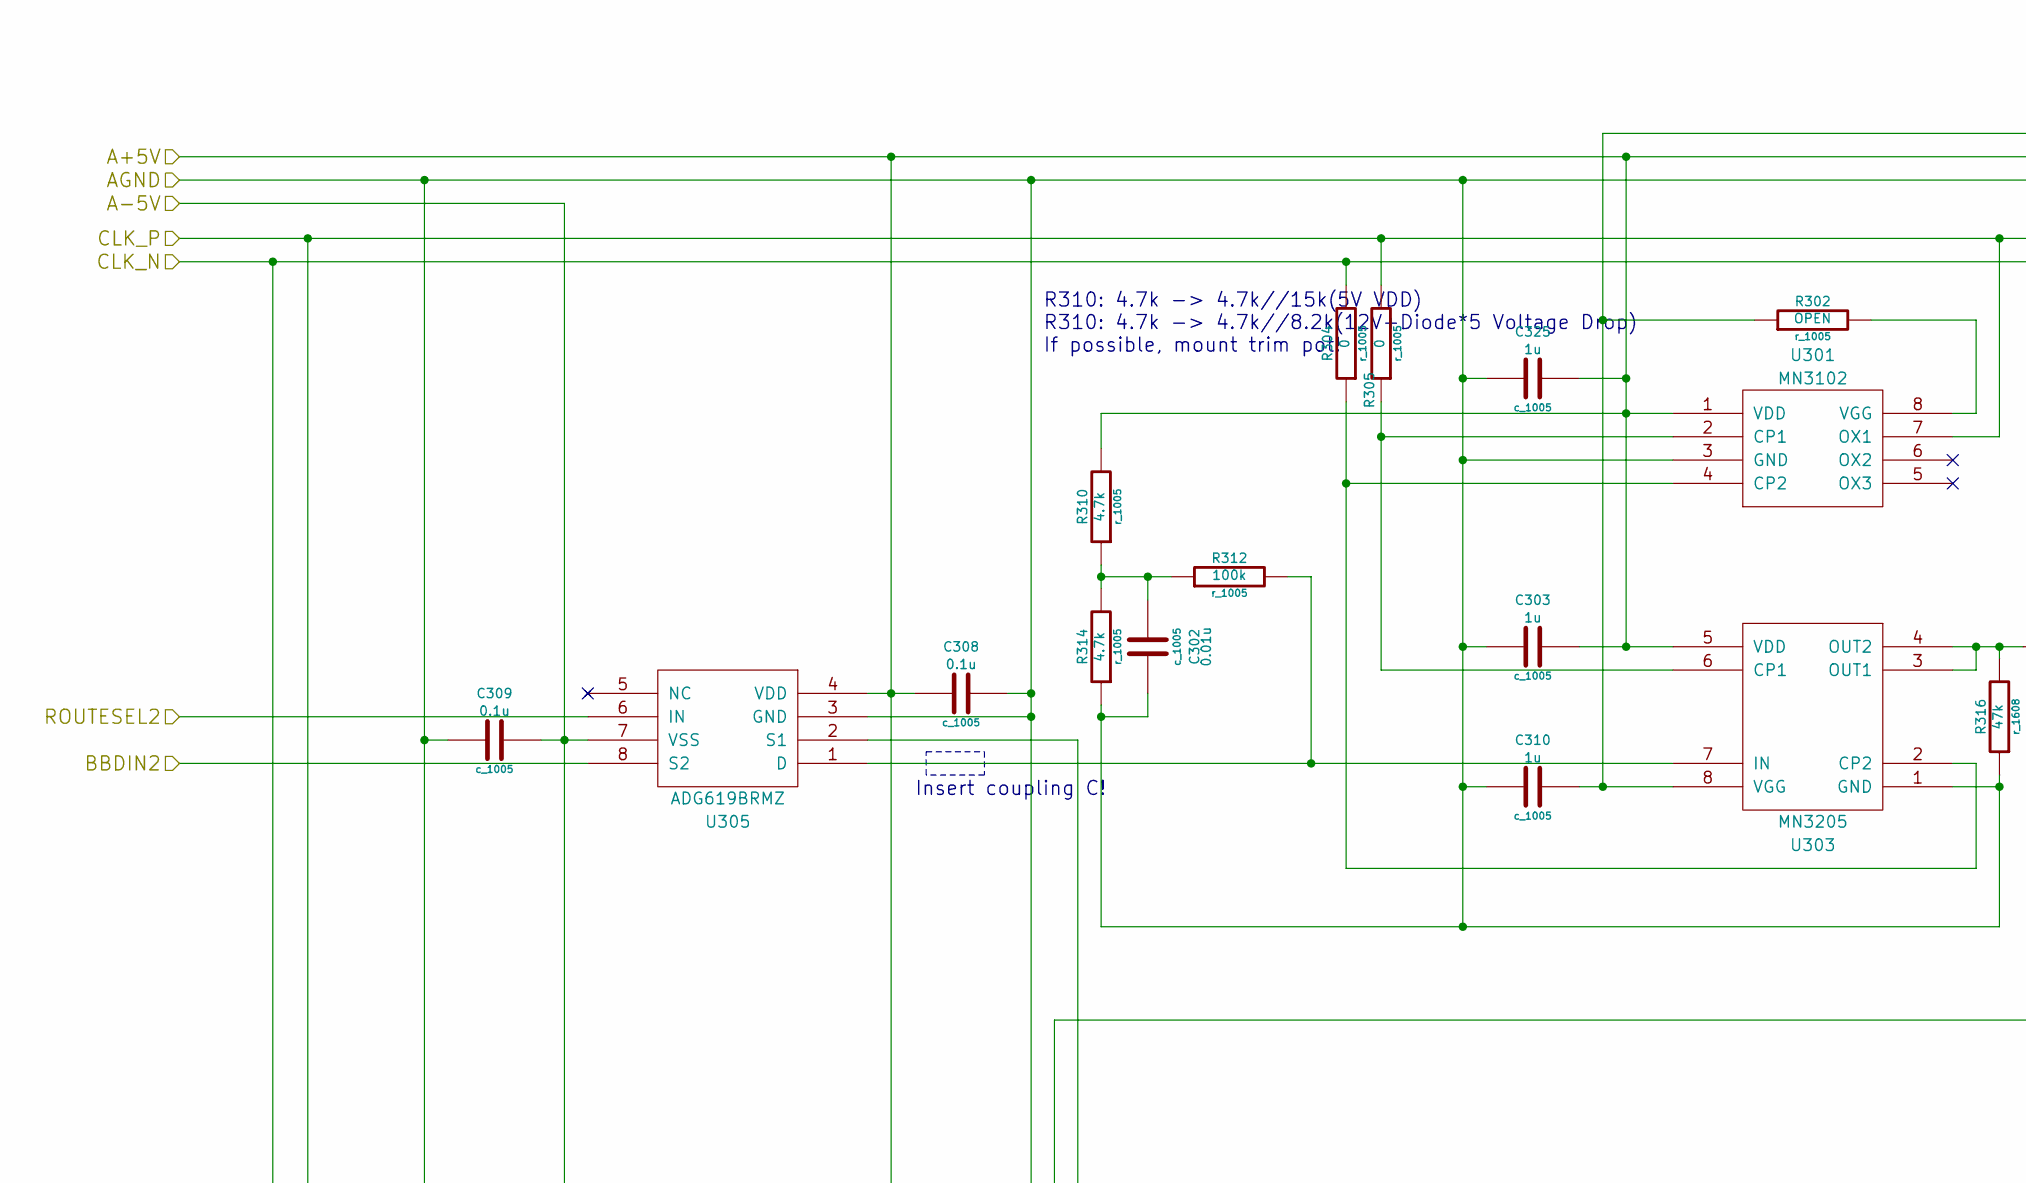
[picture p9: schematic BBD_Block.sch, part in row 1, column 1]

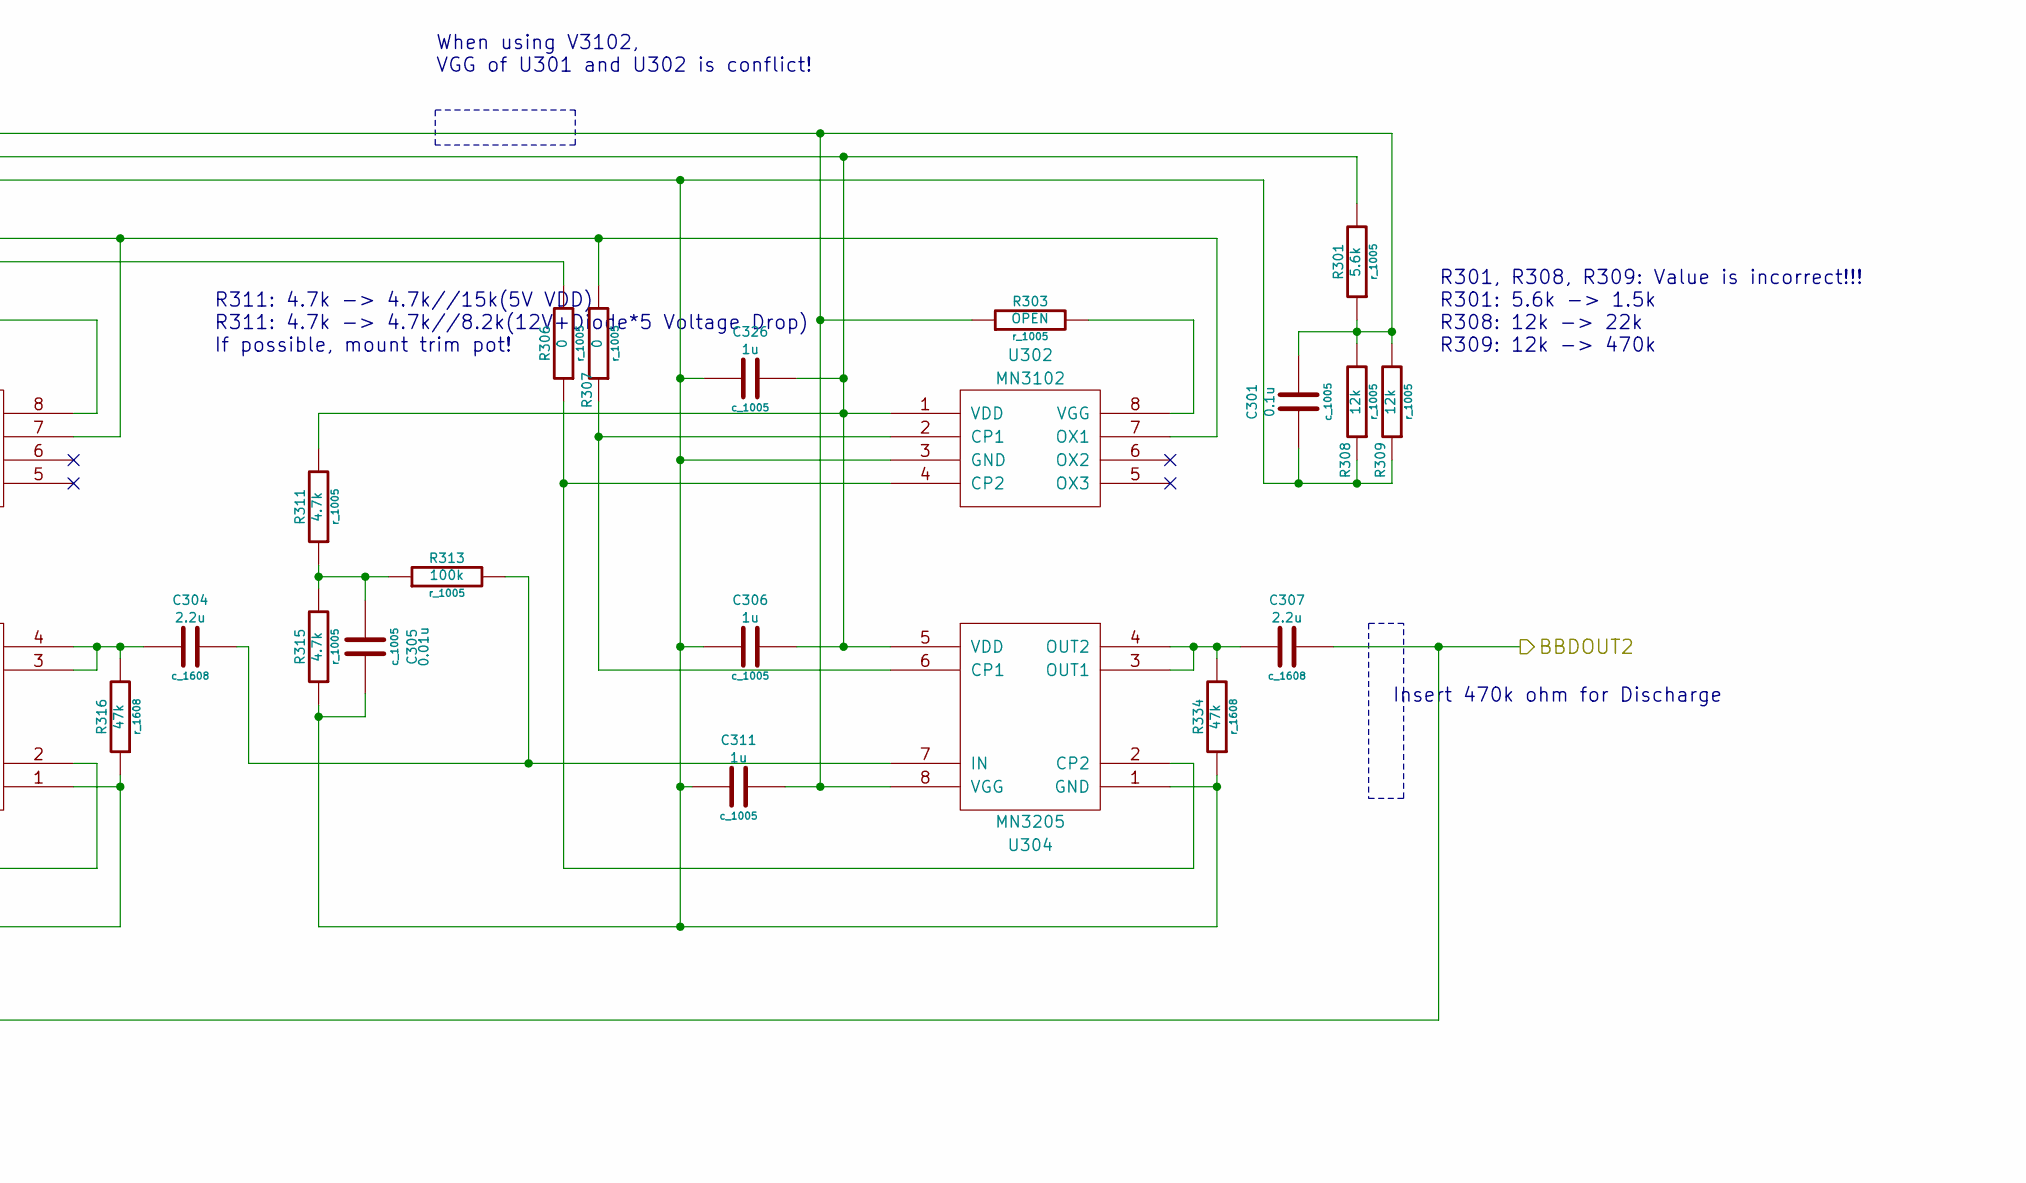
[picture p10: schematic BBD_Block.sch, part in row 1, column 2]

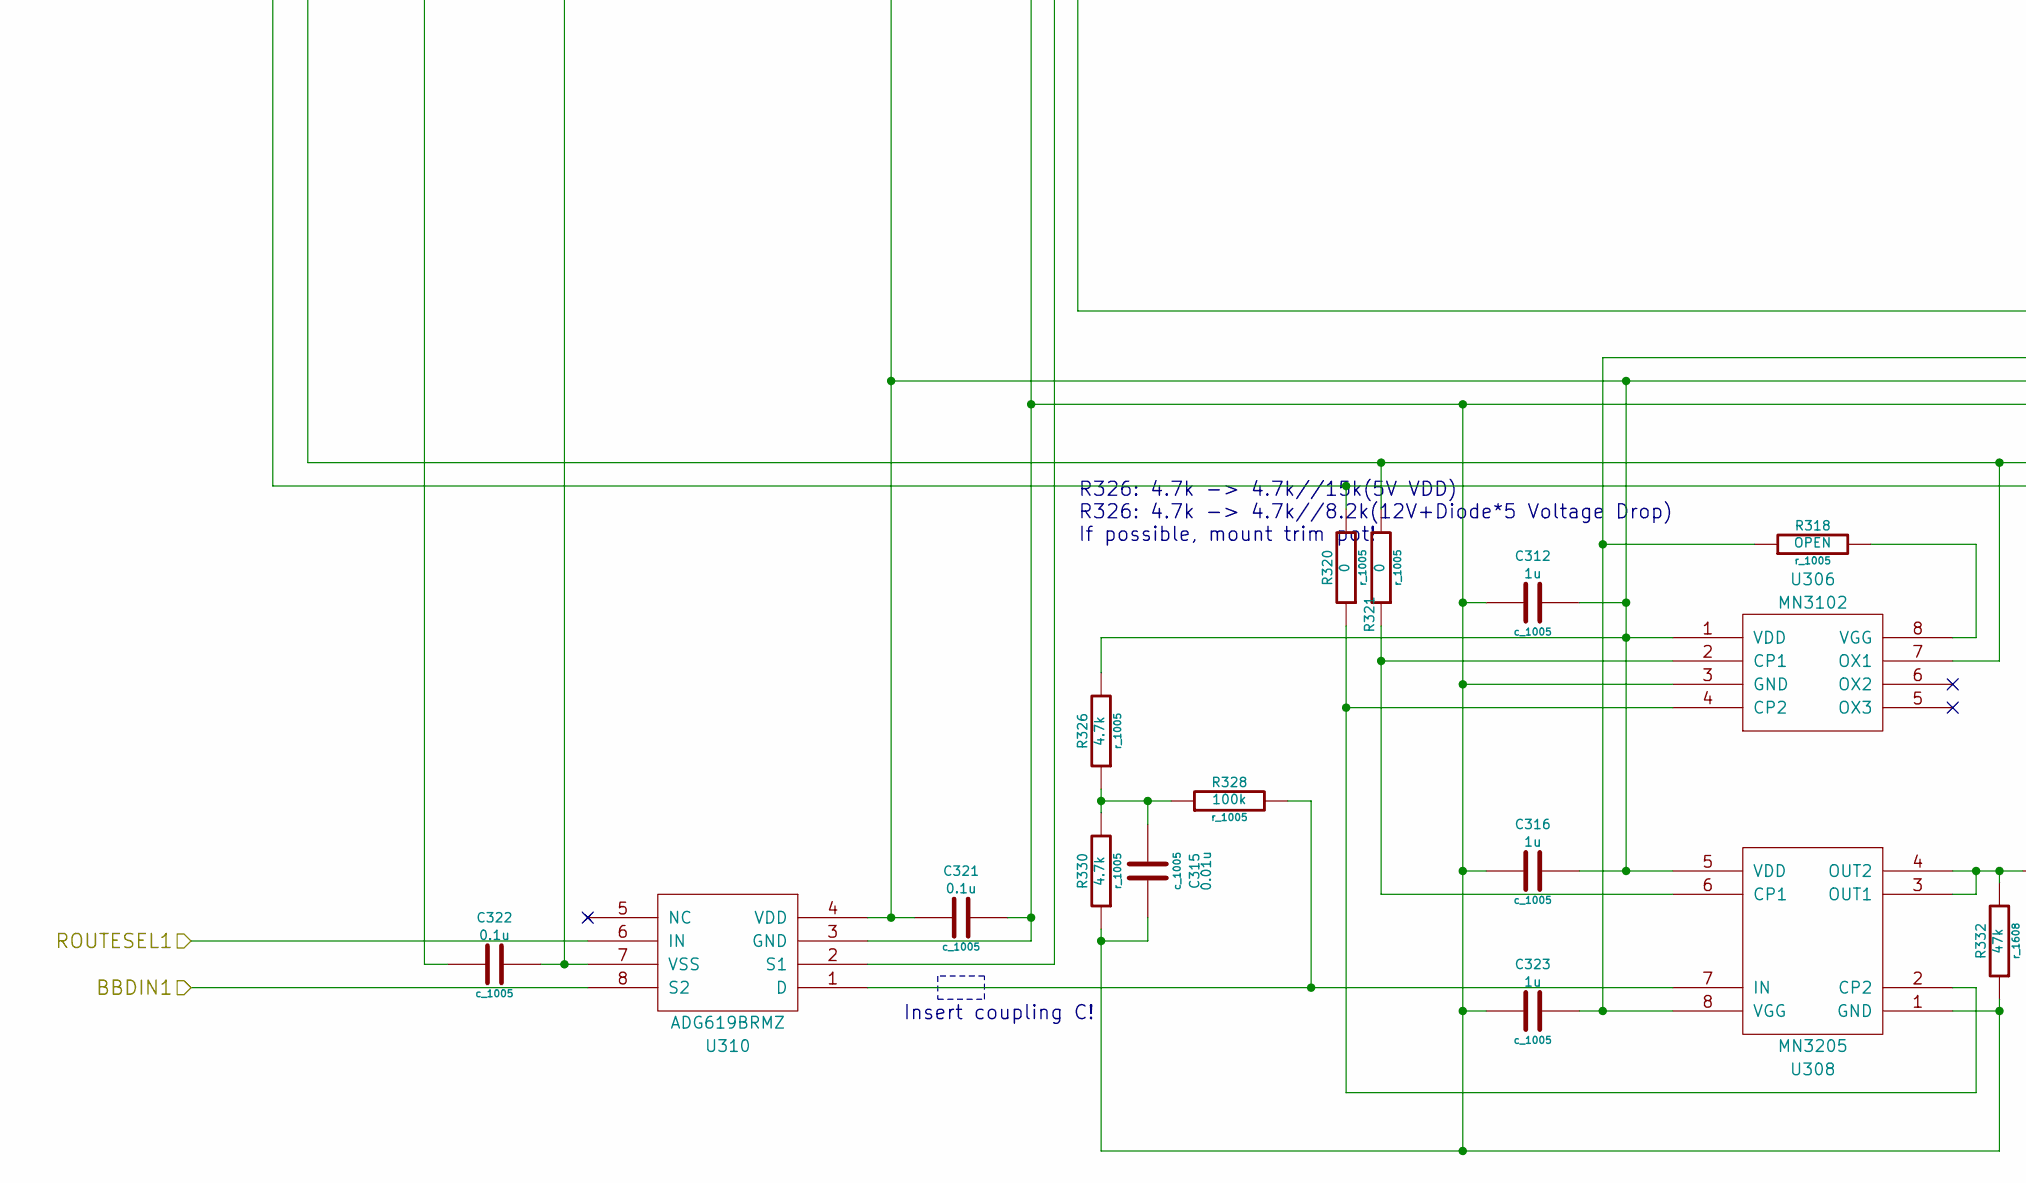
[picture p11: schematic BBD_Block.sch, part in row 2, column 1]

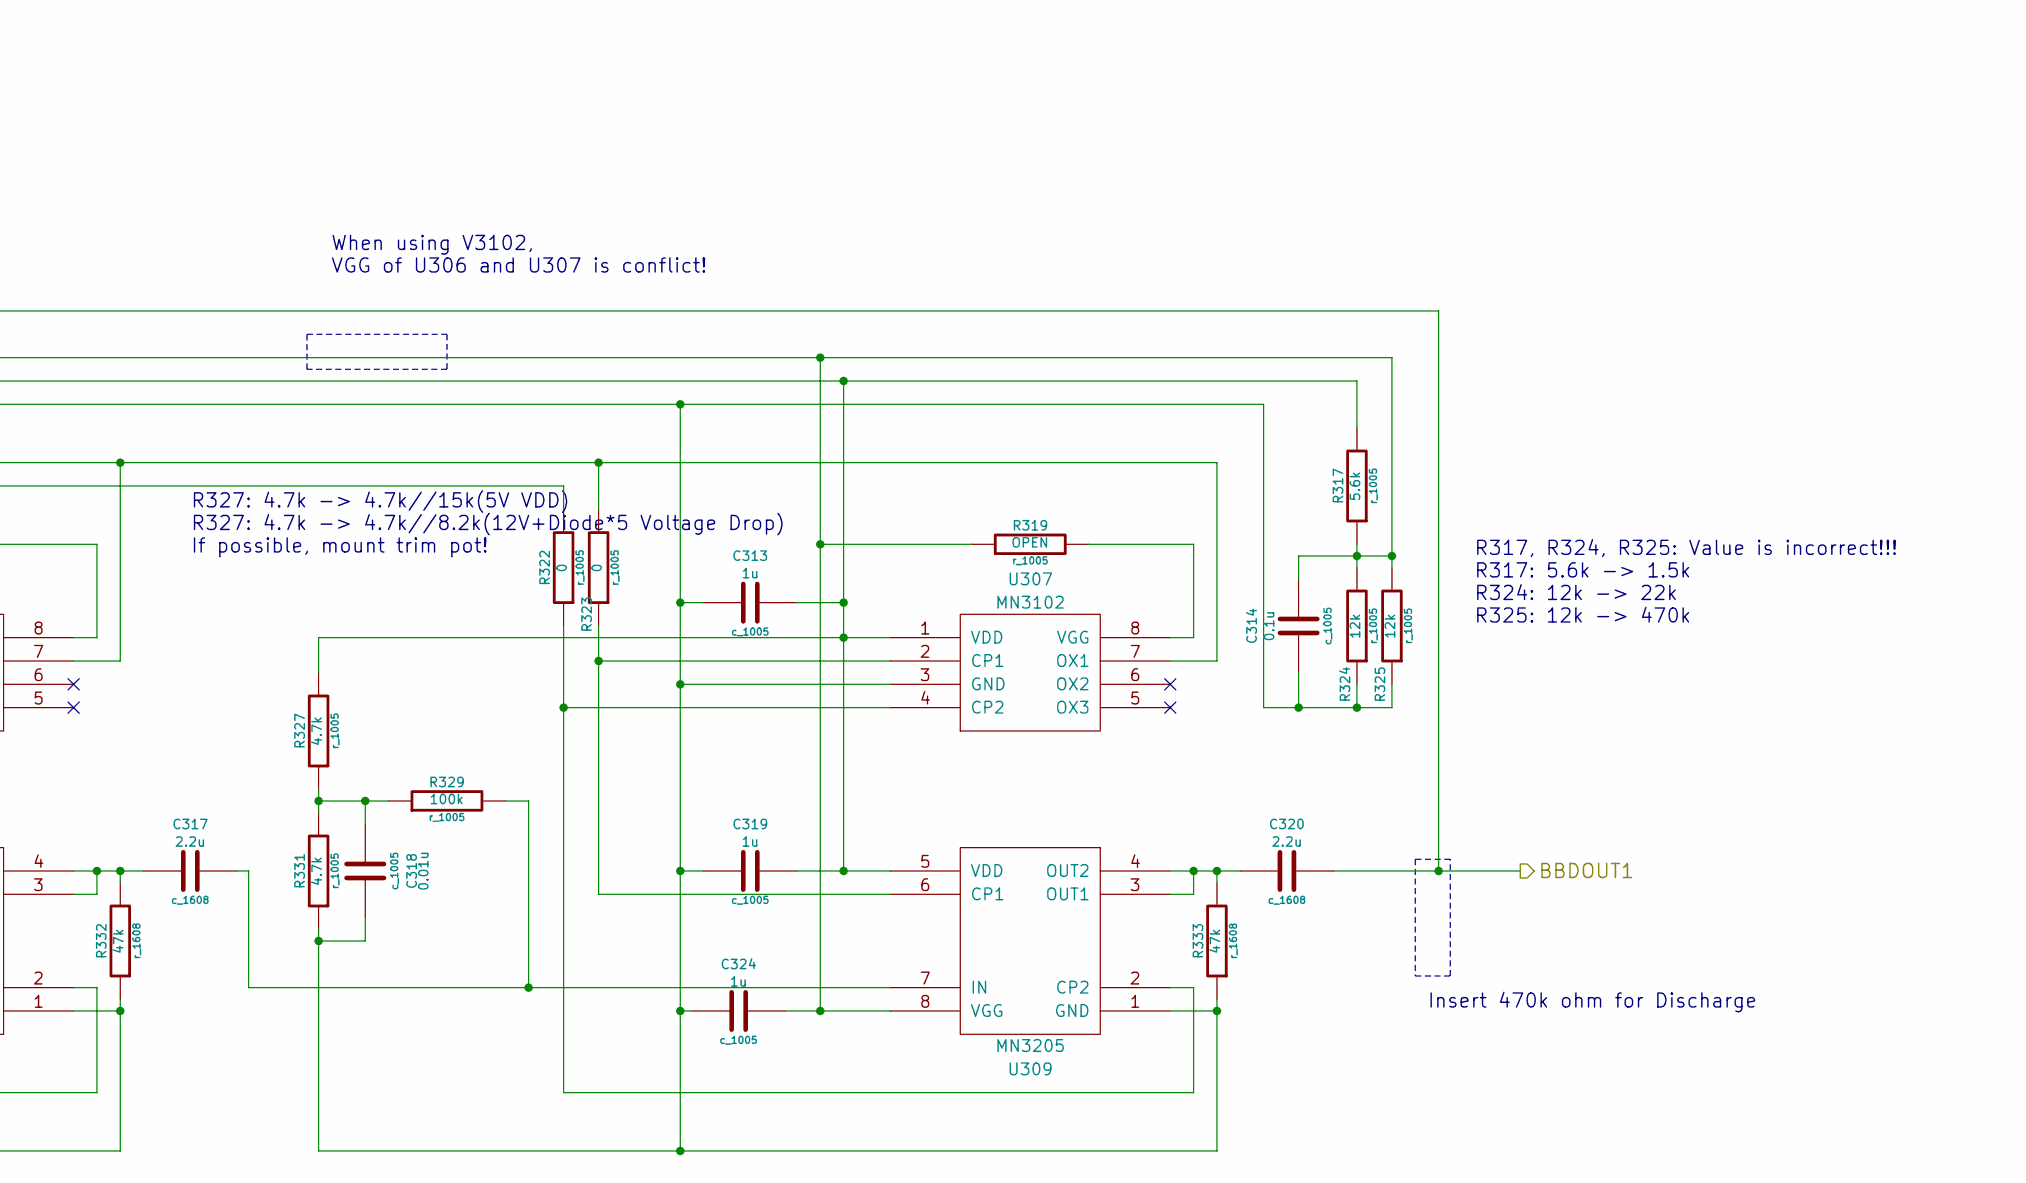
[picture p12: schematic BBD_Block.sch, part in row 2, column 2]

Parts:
C301, C308, C309, C314, C321, C322: 0.1u; c_1005
C302, C305, C315, C318: 0.01u; c_1005
C303, C306, C310, C311, C312, C313, C316, C319, C323, C324, C325, C326: 1u; c_1005
C304, C307, C317, C320: 2.2u; c_1608
R301, R317: 5.6k; r_1005
R302, R303, R318, R319: OPEN; r_1005
R304, R305, R306, R307, R320, R321, R322, R323: 0; r_1005
R308, R309, R324, R325: 12k; r_1005
R310, R311, R314, R315, R326, R327, R330, R331: 4.7k; r_1005
R312, R313, R328, R329: 100k; r_1005
R316, R332, R333, R334: 47k; r_1608
U301, U302, U306, U307: MN3102
U303, U304, U308, U309: MN3205; DIP-14-6
U305, U310: ADG619BRMZ; RM-8

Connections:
+5VA: C303.2, C306.2, C308.1, C312.2, C313.2, C316.2, C319.2, C321.1, C325.2, C326.2, R301.2, R310.2, R311.2, R317.2, R326.2, R327.2, U301.1 (VDD), U302.1 (VDD), U303.5 (VDD), U304.5 (VDD), U305.4 (VDD), U306.1 (VDD), U307.1 (VDD), U308.5 (VDD), U309.5 (VDD), U310.4 (VDD); also elsewhere on the board
-5VA: C309.2, C322.2, U305.7 (VSS), U310.7 (VSS); also elsewhere on the board
/BBD Block/BBDOUT1: C320.2, U305.2 (S1); also elsewhere on the board
/BBD Block/BBDOUT2: C307.2, U310.2 (S1); also elsewhere on the board
/BBD Block/CLK_N: R304.2, R306.2, R320.2, R322.2; also elsewhere on the board
/BBD Block/CLK_P: R305.2, R307.2, R321.2, R323.2, U301.7 (OX1), U302.7 (OX1), U306.7 (OX1), U307.7 (OX1); also elsewhere on the board
/Input/Anti Alias Filter Block/AAILIASOUT1: U310.8 (S2); also elsewhere on the board
/Input/Anti Alias Filter Block/AAILIASOUT2: U305.8 (S2); also elsewhere on the board
/Input/Anti Alias Filter Block/IN1DET: U310.6 (IN); also elsewhere on the board
/Input/Anti Alias Filter Block/IN2DET: U305.6 (IN); also elsewhere on the board
AGND: C301.1, C302.1, C303.1, C305.1, C306.1, C308.2, C309.1, C310.1, C311.1, C312.1, C313.1, C314.1, C315.1, C316.1, C318.1, C319.1, C321.2, C322.1, C323.1, C324.1, C325.1, C326.1, R308.1, R309.1, R314.1, R315.1, R316.1, R324.1, R325.1, R330.1, R331.1, R332.1, R333.1, R334.1, U301.3 (GND), U302.3 (GND), U303.1 (GND), U304.1 (GND), U305.3 (GND), U306.3 (GND), U307.3 (GND), U308.1 (GND), U309.1 (GND), U310.3 (GND); also elsewhere on the board
unnamed: C317.1, R332.2, U308.3 (OUT1), U308.4 (OUT2)
unnamed: R305.1, U301.2 (CP1), U303.6 (CP1)
unnamed: R321.1, U306.2 (CP1), U308.6 (CP1)
unnamed: C315.2, R326.1, R328.1, R330.2
unnamed: R320.1, U306.4 (CP2), U308.2 (CP2)
unnamed: R318.2, U306.8 (VGG)
unnamed: R304.1, U301.4 (CP2), U303.2 (CP2)
unnamed: C302.2, R310.1, R312.1, R314.2
unnamed: R312.2, U303.7 (IN), U305.1 (D)
unnamed: C305.2, R311.1, R313.1, R315.2
unnamed: R307.1, U302.2 (CP1), U304.6 (CP1)
unnamed: R306.1, U302.4 (CP2), U304.2 (CP2)
unnamed: C304.2, R313.2, U304.7 (IN)
unnamed: C307.1, R334.2, U304.3 (OUT1), U304.4 (OUT2)
unnamed: R319.2, U307.8 (VGG)
unnamed: C318.2, R327.1, R329.1, R331.2
unnamed: C317.2, R329.2, U309.7 (IN)
unnamed: R323.1, U307.2 (CP1), U309.6 (CP1)
unnamed: R322.1, U307.4 (CP2), U309.2 (CP2)
unnamed: C304.1, R316.2, U303.3 (OUT1), U303.4 (OUT2)
unnamed: C320.1, R333.2, U309.3 (OUT1), U309.4 (OUT2)
unnamed: C314.2, C323.2, C324.2, R317.1, R318.1, R319.1, R324.2, R325.2, U308.8 (VGG), U309.8 (VGG)
unnamed: R302.2, U301.8 (VGG)
unnamed: R328.2, U308.7 (IN), U310.1 (D)
unnamed: R303.2, U302.8 (VGG)
unnamed: C301.2, C310.2, C311.2, R301.1, R302.1, R303.1, R308.2, R309.2, U303.8 (VGG), U304.8 (VGG)

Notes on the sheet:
R317, R324, R325: Value is incorrect!!! R317: 5.6k -> 1.5k R324: 12k -> 22k R325: 12k -> 470k
R311: 4.7k -> 4.7k//15k(5V VDD) R311: 4.7k -> 4.7k//8.2k(12V+Diode*5 Voltage Drop) If possible, mount trim pot!
R301, R308, R309: Value is incorrect!!! R301: 5.6k -> 1.5k R308: 12k -> 22k R309: 12k -> 470k
When using V3102, VGG of U301 and U302 is conflict!
When using V3102, VGG of U306 and U307 is conflict!
Insert coupling C!
R327: 4.7k -> 4.7k//15k(5V VDD) R327: 4.7k -> 4.7k//8.2k(12V+Diode*5 Voltage Drop) If possible, mount trim pot!
R326: 4.7k -> 4.7k//15k(5V VDD) R326: 4.7k -> 4.7k//8.2k(12V+Diode*5 Voltage Drop) If possible, mount trim pot!
R310: 4.7k -> 4.7k//15k(5V VDD) R310: 4.7k -> 4.7k//8.2k(12V+Diode*5 Voltage Drop) If possible, mount trim pot!
Insert 470k ohm for Discharge


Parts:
C401, C402, C403, C404, C405, C406, C407: 10/10; c_2012
D401: 1SS355VMTE-17; UMD2
J401: MJ-179SMT
R401, R402: 0; r_1608
U401: NJM78M05DL1A; TO-252-3
U402: LTC1144CS8; S8_LT
U403: NJM79M05DL1A; TO-252-3

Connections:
+5VA: C402.2, C405.2, R401.1, U401.3 (VO); also elsewhere on the board
+5VD: R401.2; also elsewhere on the board
+9V: C401.2, C403.2, D401.2 (K), U401.1 (VI), U402.1 (BOOST), U402.8 (V+)
-5VA: C405.1, C407.1, U403.3 (VO); also elsewhere on the board
AGND: C401.1, C402.1, C403.1, C406.2, C407.2, J401.3, J401.4, R402.1, U401.2 (GND), U402.3 (GND), U403.1 (GND); also elsewhere on the board
DGND: R402.2; also elsewhere on the board
unnamed: C406.1, U402.5 (VOUT), U403.2 (VI)
unnamed: D401.1 (A), J401.1
unnamed: C404.1, U402.4 (CAP-)
unnamed: C404.2, U402.2 (CAP+)

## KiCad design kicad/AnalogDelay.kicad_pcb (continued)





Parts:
C501, C502, C606, C607, C609, C613, C614, C615, C616, C617, C620, C621, C622, C628, C629, C631, C635, C636, C638, C641: 0.1u; c_1005
C601, C623: 0.015u; c_1608
C602, C604, C605, C624, C626, C627: 0.01u; c_1608
C603, C608, C625, C630: 0.0033u; c_1608
C610, C632: 0.022u; c_1608
C611, C633: 0.033u; c_1608
C612, C634: 0.1u; c_1608
C618, C619, C637, C639, C640, C642: 10/10; c_2012
J601, J602: ACJS-MHDRM
R501, R502: 100; r_1005
R601, R607, R614, R615, R621, R629, R630, R632: 47k; r_1608
R602, R616: 3.3k; r_1608
R603, R608, R617, R622: 2.7k; r_1608
R604, R618: 1k; r_1608
R605, R619: 6.8k; r_1608
R606, R620: 47k; r_1005
R609, R623: 2.2k; r_1608
R610, R613, R624, R628: 820; r_1608
R611, R626: 1.5k; r_1608
R612, R627: 1.2k; r_1608
R625, R631: 33; r_1608
U601, U602, U606, U607: NJM4558M; DMP8_JRC
U603, U605: ADG619BRMZ; RM-8
U604: AD5263BRU200; RU-24
U608: AD5282BRUZ200; RU-16

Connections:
+5VA: C606.2, C607.2, C615.1, C618.2, C621.1, C622.2, C628.2, C629.2, C637.1, C638.1, C639.1, R606.2, R620.2, U601.8 (V+), U602.8 (V+), U603.4 (VDD), U604.7 (VDD), U605.4 (VDD), U606.8 (V+), U607.8 (V+), U608.5 (VDD); also elsewhere on the board
+5VD: C501.1, C502.2, U604.9 (DIS), U604.10 (VLOGIG), U604.13 (~CS~/AD0), U604.15 (~SHDN), U608.6 (~SHDN), U608.13 (VL); also elsewhere on the board
-5VA: C613.2, C614.2, C616.2, C617.1, C619.1, C620.2, C635.2, C636.2, C640.2, C641.2, C642.2, U601.4 (V-), U602.4 (V-), U603.7 (VSS), U604.18 (VSS), U605.7 (VSS), U606.4 (V-), U607.4 (V-), U608.12 (VSS); also elsewhere on the board
/BBD Block/BBDOUT1: R608.1; also elsewhere on the board
/BBD Block/BBDOUT2: R622.1; also elsewhere on the board
/Clock Cancel Filter/Output Block/BYP1IN: U603.8 (S2), U605.2 (S1); also elsewhere on the board
/Clock Cancel Filter/Output Block/BYPIN2: U603.2 (S1), U605.8 (S2); also elsewhere on the board
/Clock Cancel Filter/Output Block/MIXSEL1: R501.1, U603.6 (IN)
/Clock Cancel Filter/Output Block/MIXSEL2: R502.1, U605.6 (IN)
/Clock Cancel Filter/Output Block/OUTDET1: C609.2, J601.1, R606.1; also elsewhere on the board
/Clock Cancel Filter/Output Block/OUTDET2: C631.2, J602.1, R620.1; also elsewhere on the board
/Clock Cancel Filter/Output Block/SCL: U604.12 (CLK/SCL), U608.7 (SCL); also elsewhere on the board
/Clock Cancel Filter/Output Block/SDA: U604.11 (SDI/SDA), U608.8 (SDA); also elsewhere on the board
/Input/Anti Alias Filter Block/FBIN1_1: U604.22 (W2); also elsewhere on the board
/Input/Anti Alias Filter Block/FBIN1_2: U604.6 (W3); also elsewhere on the board
/Input/Anti Alias Filter Block/FBIN2_1: U604.19 (W4); also elsewhere on the board
/Input/Anti Alias Filter Block/FBIN2_2: U604.3 (W1); also elsewhere on the board
AGND: C606.1, C607.1, C609.1, C610.1, C611.1, C612.1, C613.1, C614.1, C615.2, C616.1, C617.2, C618.1, C619.2, C620.1, C621.2, C622.1, C628.1, C629.1, C631.1, C632.1, C633.1, C634.1, C635.1, C636.1, C637.2, C638.2, C639.2, C640.1, C641.1, C642.1, J601.4, J602.4, R630.1, R632.1, U601.3 (+), U601.5 (+), U602.3 (+), U602.5 (+), U603.3 (GND), U604.1 (B1), U604.4 (B3), U604.8 (GND), U604.21 (B4), U604.24 (B2), U605.3 (GND), U606.3 (+), U606.5 (+), U607.3 (+), U607.5 (+), U608.2 (A1), U608.11 (GND), U608.16 (A1); also elsewhere on the board
DGND: C501.2, C502.1, U604.14 (~RES~/AD1), U608.9 (AD0), U608.10 (AD1); also elsewhere on the board
unnamed: J602.6, R625.2, R630.2
unnamed: C630.1, R629.1, U608.15 (W2)
unnamed: J601.6, R631.2, R632.2
unnamed: C612.2, R604.1, R610.2, R613.1
unnamed: C602.1, R603.2, R610.1, U601.1
unnamed: C602.2, R612.2, U601.2 (-)
unnamed: C608.1, R614.1, U608.3 (W2)
unnamed: C611.2, R603.1, R609.2, R612.1
unnamed: C605.2, R613.2, U602.2 (-)
unnamed: C601.1, R605.2
unnamed: C604.2, R611.2, U601.6 (-)
unnamed: C604.1, R602.2, R609.1, U601.7
unnamed: C610.2, R602.1, R608.2, R611.1
unnamed: C601.2, R601.2, R631.1, U602.7
unnamed: C627.2, R628.2, U607.6 (-)
unnamed: C634.2, R618.1, R624.2, R628.1
unnamed: C624.1, R617.2, R624.1, U606.7
unnamed: C625.1, R621.1, U605.1 (D)
unnamed: C624.2, R627.2, U606.6 (-)
unnamed: C627.1, R618.2, U604.2 (A1), U604.20 (A4), U607.7, U608.14 (B1)
unnamed: C623.2, R615.2, R625.1, U607.1
unnamed: C623.1, R619.2
unnamed: C625.2, C630.2, R615.1, R619.1, R621.2, R629.2, U607.2 (-)
unnamed: C603.1, R607.1, U603.1 (D)
unnamed: C603.2, C608.2, R601.1, R605.1, R607.2, R614.2, U602.6 (-)
unnamed: C633.2, R617.1, R623.2, R627.1
unnamed: C626.1, R616.2, R623.1, U606.1
unnamed: C626.2, R626.2, U606.2 (-)
unnamed: C632.2, R616.1, R622.2, R626.1
unnamed: R501.2, U604.16 (SDO/O1)
unnamed: R502.2, U604.17 (NC/O2)
unnamed: C605.1, R604.2, U602.1, U604.5 (A3), U604.23 (A2), U608.4 (B1)

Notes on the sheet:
I2C ADDR: 0b00101101
I2C ADDR: 0b00101100
Add input capacitance over 2.2uF => Not Adapt
Cut for Expandor
R608: 2.7k -> 27k R611: 1.5k -> 15k R602: 3.3k -> 33k C610: 0.022u -> 0.0022u C604: 0.01u -> 0.001u
R622: 2.7k -> 27k R626: 1.5k -> 15k R616: 3.3k -> 33k C632: 0.022u -> 0.0022u C626: 0.01u -> 0.001u


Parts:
C643, C645: 1u; c_1608
C644: 0.1u; c_1005
C646: 2.2u; c_1608
C647: 1000p; c_1005
C648, C649: 22p; c_1005
CON601: AVR-ISP-6
IC601: ATTINY861A-S; SO20
P601: CONN_4X2
R633, R634, R639: 10k; r_1005
R635, R636, R637, R638, R640: 100; r_1005
SW501, SW502: 8Y1021; 8Y10
X601: 20MHz

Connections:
+5VD: C644.1, C646.2, CON601.2, IC601.5 (VCC), IC601.15 (AVCC), P601.1, R633.1, R634.1, R639.1; also elsewhere on the board
/BBD Block/CLK_N: R635.2; also elsewhere on the board
/BBD Block/CLK_P: R636.2; also elsewhere on the board
/Clock Cancel Filter/Output Block/OUTDET1: IC601.13 ((ADC4/AIN2/PCINT5)PA5); also elsewhere on the board
/Clock Cancel Filter/Output Block/OUTDET2: IC601.14 ((ADC3/ICP0/PCINT4)PA4); also elsewhere on the board
/Clock Cancel Filter/Output Block/SCL: P601.6, R634.2, R638.2; also elsewhere on the board
/Clock Cancel Filter/Output Block/SDA: P601.2, R633.2, R637.2; also elsewhere on the board
/Connect Block/ENC_A: CON601.3, IC601.3 ((SCK/USCK/SCL/~OC1B~/PCINT10)PB2), P601.5
/Connect Block/ENC_B: IC601.4 ((OC1B/PCINT11)PB3), P601.7
/Connect Block/ON_OFF: R640.2; also elsewhere on the board
/Connect Block/SW_ON_OFF: C643.2, IC601.12 ((ADC5/AIN0/PCINT6)PA6), SW501.1
/Connect Block/SW_TAP: C645.2, IC601.11 ((ADC6/AIN1/PCINT7)PA7), SW502.1
/Input/Anti Alias Filter Block/IN1DET: IC601.19 ((ADC1/DO/PCINT1)PA1); also elsewhere on the board
/Input/Anti Alias Filter Block/IN2DET: IC601.17 ((AREF/PCINT3)PA3); also elsewhere on the board
AGND: C643.1, C645.1, SW501.2, SW502.2; also elsewhere on the board
DGND: C644.2, C646.1, C647.1, C648.1, C649.1, CON601.6, IC601.6 (GND), IC601.16 (AGND), P601.4; also elsewhere on the board
unnamed: IC601.18 ((ADC2/INT1/USCK/SCL/PCINT2)PA2), R638.1
unnamed: IC601.20 ((ADC0/DI/SDA/PCINT0)PA0), R637.1
unnamed: C647.2, CON601.5, IC601.10 ((ADC10/~RESET~/PCINT15)PB7), R639.2
unnamed: C649.2, IC601.8 ((ADC8/OC1D/CLKO/XTAL2/PCINT13)PB5), P601.8, X601.2
unnamed: C648.2, IC601.7 ((ADC7/~OC1D~/CLKI/XTAL1/PCINT12)PB4), P601.3, X601.1
unnamed: IC601.9 ((ADC9/INT0/T0/PCINT14)PB6), R640.1
unnamed: CON601.1, IC601.2 ((MISO/DO/OC1A/PCINT9)PB1), R636.1
unnamed: CON601.4, IC601.1 ((MOSI/DI/SDA/~OC1A~/PCINT8)PB0), R635.1



Board: 4 copper layers, 100.0 x 80.0 mm, 266 parts (59 on the bottom side), 129 nets.

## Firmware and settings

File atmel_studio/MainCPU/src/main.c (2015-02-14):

/*
 * \file
 *
 * \brief Empty user application template
 *
 */

/**
 * \mainpage User Application template doxygen documentation
 *
 * \par Empty user application template
 *
 * Bare minimum empty user application template
 *
 * \par Content
 *
 * -# Include the ASF header files (through asf.h)
 * -# Minimal main function that starts with a call to board_init()
 * -# "Insert application code here" comment
 *
 */

/*
 * Include header files for all drivers that have been imported from
 * Atmel Software Framework (ASF).
 */
#include <asf.h>
#include "osslib/USI_TWI_Master.h"
#include "AnalogDelay.h"
#include "AD5280_5282.h"
#include "AD5263.h"
#include <string.h>

// Prototype Declaration
unsigned char TWI_Act_On_Failure_In_Last_Transmission ( unsigned char );
uint16_t Get_Tempo_to_Delay_Time_ms(uint16_t , uint8_t );
uint16_t Get_Delay_Time_ms_to_Tempo(uint16_t , uint8_t );
void EEPROM_write(unsigned char , unsigned char );
unsigned char EEPROM_read(unsigned char );
void timer0_init(void);
void timer1_init(void);
uint8_t sample_encoder(void);

	
//#define __DELAY_CYCLE_INTRINSICS__
PROGMEM_DECLARE(uint8_t, adc_to_wiper[1024]) = {
	0,0,0,0,0,0,0,0,0,0,0,0,0,0,0,0,0,0,0,0,0,0,0,0,0,0,0,0,1,1,1,1,
	1,1,1,1,1,1,1,1,1,1,1,1,1,1,1,1,1,1,1,1,1,1,1,2,2,2,2,2,2,2,2,2,
	2,2,2,2,2,2,2,2,2,2,2,2,2,2,2,2,2,3,3,3,3,3,3,3,3,3,3,3,3,3,3,3,
	3,3,3,3,3,3,3,3,3,3,4,4,4,4,4,4,4,4,4,4,4,4,4,4,4,4,4,4,4,4,4,4,
	4,4,4,5,5,5,5,5,5,5,5,5,5,5,5,5,5,5,5,5,5,5,5,5,5,5,5,6,6,6,6,6,
	6,6,6,6,6,6,6,6,6,6,6,6,6,6,6,6,6,6,7,7,7,7,7,7,7,7,7,7,7,7,7,7,
	7,7,7,7,7,7,7,7,7,8,8,8,8,8,8,8,8,8,8,8,8,8,8,8,8,8,8,8,8,8,8,9,
	9,9,9,9,9,9,9,9,9,9,9,9,9,9,9,9,9,9,9,9,9,10,10,10,10,10,10,10,10,10,10,10,
	10,10,10,10,10,10,10,10,10,10,11,11,11,11,11,11,11,11,11,11,11,11,11,11,11,11,11,11,11,11,12,12,
	12,12,12,12,12,12,12,12,12,12,12,12,12,12,12,12,12,12,13,13,13,13,13,13,13,13,13,13,13,13,13,13,
	13,13,13,13,13,14,14,14,14,14,14,14,14,14,14,14,14,14,14,14,14,14,14,14,15,15,15,15,15,15,15,15,
	15,15,15,15,15,15,15,15,15,15,16,16,16,16,16,16,16,16,16,16,16,16,16,16,16,16,16,16,17,17,17,17,
	17,17,17,17,17,17,17,17,17,17,17,17,17,18,18,18,18,18,18,18,18,18,18,18,18,18,18,18,18,18,19,19,
	19,19,19,19,19,19,19,19,19,19,19,19,19,19,19,20,20,20,20,20,20,20,20,20,20,20,20,20,20,20,20,21,
	21,21,21,21,21,21,21,21,21,21,21,21,21,21,22,22,22,22,22,22,22,22,22,22,22,22,22,22,22,23,23,23,
	23,23,23,23,23,23,23,23,23,23,23,23,24,24,24,24,24,24,24,24,24,24,24,24,24,24,25,25,25,25,25,25,
	25,25,25,25,25,25,25,25,26,26,26,26,26,26,26,26,26,26,26,26,26,26,27,27,27,27,27,27,27,27,27,27,
	27,27,27,28,28,28,28,28,28,28,28,28,28,28,28,28,29,29,29,29,29,29,29,29,29,29,29,29,30,30,30,30,
	30,30,30,30,30,30,30,30,31,31,31,31,31,31,31,31,31,31,31,31,32,32,32,32,32,32,32,32,32,32,32,32,
	33,33,33,33,33,33,33,33,33,33,33,34,34,34,34,34,34,34,34,34,34,34,35,35,35,35,35,35,35,35,35,35,
	36,36,36,36,36,36,36,36,36,36,36,37,37,37,37,37,37,37,37,37,37,38,38,38,38,38,38,38,38,38,39,39,
	39,39,39,39,39,39,39,39,40,40,40,40,40,40,40,40,40,41,41,41,41,41,41,41,41,41,42,42,42,42,42,42,
	42,42,42,43,43,43,43,43,43,43,43,44,44,44,44,44,44,44,44,44,45,45,45,45,45,45,45,45,46,46,46,46,
	46,46,46,46,47,47,47,47,47,47,47,48,48,48,48,48,48,48,48,49,49,49,49,49,49,49,50,50,50,50,50,50,
	50,51,51,51,51,51,51,51,52,52,52,52,52,52,52,53,53,53,53,53,53,54,54,54,54,54,54,55,55,55,55,55,
	55,56,56,56,56,56,56,57,57,57,57,57,57,58,58,58,58,58,58,59,59,59,59,59,60,60,60,60,60,60,61,61,
	61,61,61,62,62,62,62,62,63,63,63,63,63,64,64,64,64,64,65,65,65,65,66,66,66,66,66,67,67,67,67,68,
	68,68,68,68,69,69,69,69,70,70,70,70,71,71,71,71,72,72,72,72,73,73,73,73,74,74,74,75,75,75,75,76,
	76,76,77,77,77,77,78,78,78,79,79,79,80,80,80,81,81,81,82,82,82,83,83,83,84,84,84,85,85,85,86,86,
	87,87,87,88,88,89,89,89,90,90,91,91,92,92,92,93,93,94,94,95,95,96,96,97,97,98,98,99,99,100,101,101,
	102,102,103,103,104,105,105,106,107,107,108,109,109,110,111,112,112,113,114,115,116,117,117,118,119,120,121,122,123,124,125,127,
	128,129,130,131,133,134,136,137,139,140,142,144,146,148,150,152,154,157,160,162,166,169,173,177,182,188,195,203,213,228,254,255
};

/*PROGMEM_DECLARE(uint8_t, adc_to_wiper[1024]) = {
0,0,6,22,34,43,50,56,61,66,70,74,78,81,84,87,
89,92,94,96,98,100,102,104,105,107,109,110,112,113,114,116,
117,118,119,120,122,123,124,125,126,127,128,129,130,131,131,132,
133,134,135,136,136,137,138,139,139,140,141,141,142,143,143,144,
145,145,146,146,147,148,148,149,149,150,150,151,152,152,153,153,
154,154,155,155,156,156,156,157,157,158,158,159,159,160,160,160,
161,161,162,162,162,163,163,164,164,164,165,165,166,166,166,167,
167,167,168,168,168,169,169,169,170,170,170,171,171,171,172,172,
172,173,173,173,174,174,174,174,175,175,175,176,176,176,177,177,
177,177,178,178,178,178,179,179,179,179,180,180,180,181,181,181,
181,182,182,182,182,183,183,183,183,183,184,184,184,184,185,185,
185,185,186,186,186,186,186,187,187,187,187,188,188,188,188,188,
189,189,189,189,189,190,190,190,190,190,191,191,191,191,191,192,
192,192,192,192,193,193,193,193,193,193,194,194,194,194,194,195,
195,195,195,195,195,196,196,196,196,196,196,197,197,197,197,197,
198,198,198,198,198,198,198,199,199,199,199,199,199,200,200,200,
200,200,200,201,201,201,201,201,201,201,202,202,202,202,202,202,
203,203,203,203,203,203,203,204,204,204,204,204,204,204,205,205,
205,205,205,205,205,205,206,206,206,206,206,206,206,207,207,207,
207,207,207,207,207,208,208,208,208,208,208,208,209,209,209,209,
209,209,209,209,210,210,210,210,210,210,210,210,210,211,211,211,
211,211,211,211,211,212,212,212,212,212,212,212,212,212,213,213,
213,213,213,213,213,213,214,214,214,214,214,214,214,214,214,214,
215,215,215,215,215,215,215,215,215,216,216,216,216,216,216,216,
216,216,217,217,217,217,217,217,217,217,217,217,218,218,218,218,
218,218,218,218,218,218,219,219,219,219,219,219,219,219,219,219,
220,220,220,220,220,220,220,220,220,220,220,221,221,221,221,221,
221,221,221,221,221,221,222,222,222,222,222,222,222,222,222,222,
222,223,223,223,223,223,223,223,223,223,223,223,224,224,224,224,
224,224,224,224,224,224,224,224,225,225,225,225,225,225,225,225,
225,225,225,225,226,226,226,226,226,226,226,226,226,226,226,226,
227,227,227,227,227,227,227,227,227,227,227,227,227,228,228,228,
228,228,228,228,228,228,228,228,228,229,229,229,229,229,229,229,
229,229,229,229,229,229,229,230,230,230,230,230,230,230,230,230,
230,230,230,230,231,231,231,231,231,231,231,231,231,231,231,231,
231,231,232,232,232,232,232,232,232,232,232,232,232,232,232,232,
233,233,233,233,233,233,233,233,233,233,233,233,233,233,233,234,
234,234,234,234,234,234,234,234,234,234,234,234,234,234,235,235,
235,235,235,235,235,235,235,235,235,235,235,235,235,236,236,236,
236,236,236,236,236,236,236,236,236,236,236,236,236,237,237,237,
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
};*/

void timer0_init() {
	OCR0A = 250;		// 16MHz/64/OCR0A=1kHz, OCR0A=250
	// Configure Timer/Counter to CTC mode, and set desired prescaler
	TCCR0A = (1 << WGM00);
	TCCR0B = (0 << CS02 | 1 << CS01 | 1 << CS00);
	// Enable interrupt for compare match
	TIMSK = 1 << OCIE0A;
}

void timer1_init() {
	//! PLL Start Setting
	TCCR1B = 1 << PSR1;
	PLLCSR = 1 << PLLE;
	delay_us(200);
	while(!(PLLCSR & (1<<PLOCK)));
	PLLCSR |= (1<<PCKE);
	
	//OCR1A = 488; 
	//OCR1C = 976; 
	//TCCR1B = 0b0100 << CS10;
	TCCR1A = (0 << COM1A1 | 1 << COM1A0 | 0 << COM1B1 | 1 << COM1B0 | 0 << FOC1B | 0 << FOC1A | 1 << PWM1A | 0 << PWM1B);
	TIMSK |= 0<<TOIE1;
	
	
}

uint8_t sample_encoder() {
	
	static uint8_t i;
	
	i = (i << 2) + (ioport_get_pin_level(ENC_B) << 1 | ioport_get_pin_level(ENC_A));
	i &= 15;
	
	switch (i) { 
	case 0b00000111: 
		return ENCODER_INCREMENT;
		break;
	case 0b00001101: 
		return ENCODER_DECREMENT;
		break;
	default:
		break;
	}
	return ENCODER_ERROR;
}

uint16_t Get_Delay_Time_ms_to_Tempo(uint16_t delay_time_ms, uint8_t delay_mode) {
	// delay_time_ms: delay time[msec]
	// delay_mode   : 0:Quarter note, 1: Dotted Eighth note, 2: Eighth note, 3: Dotted sixteenth note, 4: Triplet, 5: Triplet eighth
	// return       : Tempo
	uint16_t tempo = 0;
	
	switch(delay_mode) {
		case 0: 
			tempo = 60000UL/delay_time_ms;		// quarter note
			break;
		case 1: 
			tempo = 60000UL/delay_time_ms*3/4;	// Dotted eighth note
			break;
		case 2: 
			tempo = 60000UL/delay_time_ms*1/2;	// eighth note
			break;
		case 3: 
			tempo = 60000UL/delay_time_ms*3/8;	// Dotted sixteenth note
			break; 
		case 4:
			tempo = 60000UL/delay_time_ms*1/3;	// Triplet
			break;
		case 5: 
			tempo = 60000UL/delay_time_ms*1/6;	// Triplet eighth
			break; 
		default:
			break;
	}
	return tempo; 
}

uint16_t Get_Tempo_to_Delay_Time_ms(uint16_t tempo, uint8_t delay_mode) {
	// tempo
	// delay_mode   : 0:Quarter note, 1: Dotted quarter note, 2: Eighth note, 3: Dotted eighth note, 4: Triplet
	// return - delay_time_ms: delay time[msec]
	uint32_t delay_time_ms = 0;
	
	switch(delay_mode) {
		case 0:
			delay_time_ms = 60000/tempo;
			break;
		case 1:
			delay_time_ms = 60000/tempo*3/4;
			break;
		case 2:
			delay_time_ms = 60000/tempo*1/2;
			break;
		case 3: 
			delay_time_ms = 60000/tempo*3/8; 
			break; 
		case 4:
			delay_time_ms = 60000/tempo*1/3;
			break;
		case 5:
			delay_time_ms = 60000/tempo*1/6;
			break;
		default:
			break;
	}
	return (uint16_t)(delay_time_ms);
}
	
unsigned char TWI_Act_On_Failure_In_Last_Transmission ( unsigned char TWIerrorMsg )
{
	// A failure has occurred, use TWIerrorMsg to determine the nature of the failure
	// and take appropriate actions.
	// Se header file for a list of possible failures messages.
	asm("nop");
	return TWIerrorMsg;
}

void EEPROM_write(unsigned char ucAddress, unsigned char ucData)
{
	irqflags_t flags;
	flags = cpu_irq_save();
	
	/* Wait for completion of previous write */
	while(EECR & (1<<EEPE))
	;
	/* Set Programming mode */
	EECR = (0<<EEPM1)|(0<<EEPM0);
	/* Set up address and data registers */
	EEAR = ucAddress;
	EEDR = ucData;
	/* Write logical one to EEMPE */
	EECR |= (1<<EEMPE);
	/* Start eeprom write by setting EEPE */
	EECR |= (1<<EEPE);
	
	cpu_irq_restore(flags);
}

unsigned char EEPROM_read(unsigned char ucAddress)
{
	irqflags_t flags;
	flags = cpu_irq_save();

	/* Wait for completion of previous write */
	while(EECR & (1<<EEPE))
	;
	/* Set up address register */
	EEAR = ucAddress;
	/* Start eeprom read by writing EERE */
	EECR |= (1<<EERE);
	cpu_irq_restore(flags);
	/* Return data from data register */
	return EEDR;
}
int main (void)
{
	// Variable for TWI-I2C
	unsigned char messageBuf[MESSAGEBUF_SIZE];
	unsigned char TWI_targetSlaveAddress, temp;
	// Variable for Analog Delay Registers
	uint8_t loop_counter = 0;		// Main Loop Counter
	uint8_t sample_switch0 = 0;		// SW0 sample record
	uint8_t sw0_push_count =0;		// SW0 push timer/counter per 10msec
	uint8_t sample_switch1 = 0;		// SW1 sample record
	uint16_t sw1_push_count =0;		// SW1 push timer/counter per 1msec;
	uint16_t sw1_tap_count =0x3FF;		// SW1 tap timer/counter per 1msec	
	uint8_t DCR0 = 0x00;
	uint8_t DCR1 = get_bit_mask(TEMPO_TIME_BIT);
	uint8_t DCR2 = 0x00;
	uint16_t TPR = 120;
	uint16_t DTR = Get_Tempo_to_Delay_Time_ms(TPR, ((DCR2&(get_bit_mask(DTYPE2_BIT)|get_bit_mask(DTYPE1_BIT)|get_bit_mask(DTYPE0_BIT)))>>DTYPE0_BIT));	// Transfer Gotten Delay Time to Tempo
	uint8_t VOLR = 0x00;
	uint8_t FXVOLUME[2] = {0};
	uint8_t FBVR = 0x00;
	uint8_t FBVOLUME[4] = {0};
	uint16_t OCR = 250;				// Initialize Pre-OCR Register
	uint8_t LCD_CMD = LCD_CMD_TRANSFER_REG;
	uint8_t i;
	uint8_t i2c_send_time_counter = 0; 
	unsigned char msg_save[] = "Saving  ";
	unsigned char msg_load[] = "Loading ";
		
	board_init();
	
	// Insert application code here, after the board has been initialized.
	USIPP = 0x01;
	USI_TWI_Master_Initialise();
	timer0_init();
	timer1_init();
	adc_init(ADC_PRESCALER_DIV32);
	//cpu_irq_enable();
	delay_ms(500);					// Wait for Voltage rise up
	
	// Main Loop Start
	while(1) {
		if(TIFR & (1 << OCF0A)) {	// Interrupt per 1msec by timer/counter0
			// Transfer Display Data
			if(loop_counter==5 || loop_counter==0) {
				// Set Display Data to LCD
				//I2C_Transfer(ADDR, CMD, DATA, databyte, R/W);
				TWI_targetSlaveAddress = LCD_ADDR_BYTE;
				messageBuf[0]  = (TWI_targetSlaveAddress<<TWI_ADR_BITS) | (FALSE<<TWI_READ_BIT); // The first byte must always consit of General Call code or the TWI slave address.
				messageBuf[1]  = LCD_CMD;             // The first byte is used for commands.
				messageBuf[2]  = DCR0;
				messageBuf[3]  = DCR1;
				messageBuf[4]  = (DTR>>8);
				messageBuf[5]  = (DTR&0xFF);
				messageBuf[6]  = (TPR>>8);
				messageBuf[7]  = (TPR&0xFF);
				messageBuf[8]  = VOLR;
				messageBuf[9]  = FBVR;
				messageBuf[10] = DCR2;
				temp = USI_TWI_Start_Transceiver_With_Data(messageBuf, 11);
				if (!temp)    // One of the operations failed.
				{             // Use TWI status information to detemine cause of failure and take appropriate actions.
					TWI_Act_On_Failure_In_Last_Transmission( USI_TWI_Get_State_Info( ) );
					asm("nop"); // Put own code here.
				}
			}
	
			// Input/Output Jack Detection
			if(loop_counter==3) {
				DCR0 = (DCR0 & ~(0b00111010)) | (ioport_get_port_level(PORT_DET, 0b00111010));
			}
			
			// SW0 State Check
			if(loop_counter==4) {
				sample_switch0 =sample_switch0 << 1 | ioport_get_pin_level(SW0);
				if((sample_switch0 & 0x03)==0x00) {
					if(sw0_push_count!=0xFF) {
						sw0_push_count++;
						if((LCD_CMD!=LCD_CMD_DISPLAY_LOAD)&&(LCD_CMD!=LCD_CMD_DISPLAY_SAVE)) {
							if(sw0_push_count==100) {		// Count 1sec
								// Long push
								if(sw1_push_count>500) {	// Change Display Mode
									DCR1 = (DCR1 & ~(get_bit_mask(TEMPO_TIME_BIT))) | (~DCR1 & get_bit_mask(TEMPO_TIME_BIT));
									sw1_push_count = 1023;	// timeout sw1_push_count
								}
								else {
									switch(DCR0 & (get_bit_mask(INDET0_BIT)|get_bit_mask(INDET1_BIT)|get_bit_mask(OUTDET0_BIT)|get_bit_mask(OUTDET1_BIT))) {
										case (get_bit_mask(OUTDET0_BIT)|get_bit_mask(OUTDET1_BIT)):
											// Toggle MIX/DRY mode
											DCR0 = (DCR0 & ~(get_bit_mask(DRY_MIX_BIT))) | (~DCR0 & get_bit_mask(DRY_MIX_BIT));
										break;
										case (get_bit_mask(INDET0_BIT)|get_bit_mask(OUTDET0_BIT)|get_bit_mask(OUTDET1_BIT)): 
											// Toggle MIX/DRY mode
											DCR0 = (DCR0 & ~(get_bit_mask(DRY_MIX_BIT))) | (~DCR0 & get_bit_mask(DRY_MIX_BIT));
										break;
										case (get_bit_mask(INDET1_BIT)|get_bit_mask(OUTDET0_BIT)|get_bit_mask(OUTDET1_BIT)): 
											// Toggle MIX/DRY mode
											DCR0 = (DCR0 & ~(get_bit_mask(DRY_MIX_BIT))) | (~DCR0 & get_bit_mask(DRY_MIX_BIT));
										break;
										default: 
										break;
									}
								}
							}
						}
					}
				}
				else if((sample_switch0 & 0x0F)==0x01) {
					if((sw0_push_count > 0) && (sw0_push_count < 25) && (sw1_push_count == 0)) {
						// Short_push
						// Effect ON/OFF
						DCR0 = (DCR0 & ~(get_bit_mask(ON_OFF_BIT))) | (~DCR0 & get_bit_mask(ON_OFF_BIT));
						ioport_set_pin_level(ON_OFF, DCR0&get_bit_mask(ON_OFF_BIT));
					}
					sw0_push_count = 0;
				}
			}
			
			sample_switch1 = sample_switch1 << 1 | ioport_get_pin_level(SW1);
			// SW1 State Check for TAP(every 1ms Main Loop)
			if((sample_switch1 & 0x03)==0x02) {
				if((LCD_CMD!=LCD_CMD_DISPLAY_LOAD)&&(LCD_CMD!=LCD_CMD_DISPLAY_SAVE)) {
					if(sw1_tap_count!=0x3FF){
						sw1_tap_count = (uint16_t)Get_Delay_Time_ms_to_Tempo(sw1_tap_count, 0);
						if((sw1_tap_count>=MIN_DELAY_TEMPO) && (sw1_tap_count<=MAX_DELAY_TEMPO)) {
							TPR = (TPR + sw1_tap_count) >> 1;			// If Tap < 1023msec, Write Delay Time
							DTR = Get_Tempo_to_Delay_Time_ms(TPR, ((DCR2&(get_bit_mask(DTYPE2_BIT)|get_bit_mask(DTYPE1_BIT)|get_bit_mask(DTYPE0_BIT)))>>DTYPE0_BIT));	// Transfer Gotten Delay Time to Tempo
						}
					}
					sw1_tap_count = 0;					// Clear at pushing SW1
				}
				else {
					switch(LCD_CMD) {
						case LCD_CMD_DISPLAY_SAVE: 
							// Save Tempo
							EEPROM_write((DCR1&(get_bit_mask(MBANK0_BIT)|get_bit_mask(MBANK1_BIT)|get_bit_mask(MBANK2_BIT)))+0x00, (unsigned char)(DTR&0xFF));
							EEPROM_write((DCR1&(get_bit_mask(MBANK0_BIT)|get_bit_mask(MBANK1_BIT)|get_bit_mask(MBANK2_BIT)))+0x01, (unsigned char)(DTR>>8));
							EEPROM_write((DCR1&(get_bit_mask(MBANK0_BIT)|get_bit_mask(MBANK1_BIT)|get_bit_mask(MBANK2_BIT)))+0x02, (unsigned char)(TPR&0xFF));
							EEPROM_write((DCR1&(get_bit_mask(MBANK0_BIT)|get_bit_mask(MBANK1_BIT)|get_bit_mask(MBANK2_BIT)))+0x03, (unsigned char)(TPR>>8));
							EEPROM_write((DCR1&(get_bit_mask(MBANK0_BIT)|get_bit_mask(MBANK1_BIT)|get_bit_mask(MBANK2_BIT)))+0x04, (unsigned char)(DCR2));
						break;
						case LCD_CMD_DISPLAY_LOAD:
							// Load Tempo
							DTR = EEPROM_read((DCR1&(get_bit_mask(MBANK0_BIT)|get_bit_mask(MBANK1_BIT)|get_bit_mask(MBANK2_BIT)))+0x00);
							DTR = (DTR&0x00FF) | (EEPROM_read((DCR1&(get_bit_mask(MBANK0_BIT)|get_bit_mask(MBANK1_BIT)|get_bit_mask(MBANK2_BIT)))+0x01)<<8);
							TPR = EEPROM_read((DCR1&(get_bit_mask(MBANK0_BIT)|get_bit_mask(MBANK1_BIT)|get_bit_mask(MBANK2_BIT)))+0x02);
							TPR = (TPR&0x00FF) | (EEPROM_read((DCR1&(get_bit_mask(MBANK0_BIT)|get_bit_mask(MBANK1_BIT)|get_bit_mask(MBANK2_BIT)))+0x03)<<8);
							DCR2 = EEPROM_read((DCR1&(get_bit_mask(MBANK0_BIT)|get_bit_mask(MBANK1_BIT)|get_bit_mask(MBANK2_BIT)))+0x04);
						break;
						default:
						break;
					}
				}
				
			}
			else {
				if(sw1_tap_count!=0x3FF) {
					sw1_tap_count++;				// Count up till 1023
				}
			}
			// SW1 State Check for PUSH(every 1ms Main Loop)
			if((LCD_CMD!=LCD_CMD_DISPLAY_LOAD)&&(LCD_CMD!=LCD_CMD_DISPLAY_SAVE)) {
				if((sample_switch1 & 0x03)==0x00) {
					if(sw1_push_count!=0x3FF) {
						sw1_push_count++;
						if(sw1_push_count==1000) {		// Count 1sec
							// Long push Detect
							// Toggle Delay mode
							if((DCR2&(get_bit_mask(DTYPE2_BIT)|get_bit_mask(DTYPE1_BIT)|get_bit_mask(DTYPE0_BIT)))>>DTYPE0_BIT == 0x05){
								DCR2 = (DCR2&~(get_bit_mask(DTYPE2_BIT)|get_bit_mask(DTYPE1_BIT)|get_bit_mask(DTYPE0_BIT)));
							}
							else {
								DCR2++;
							}
							DTR = Get_Tempo_to_Delay_Time_ms(TPR, ((DCR2&(get_bit_mask(DTYPE2_BIT)|get_bit_mask(DTYPE1_BIT)|get_bit_mask(DTYPE0_BIT)))>>DTYPE0_BIT));
						}
					}
				}
				else if((sample_switch1 & 0x0F)==0x01) {
					sw1_push_count = 0;
				}				
			}
			
			// Volume Pot ADC
			if(loop_counter==6) {
				VOLR = PROGMEM_READ_BYTE(&(adc_to_wiper[adc_read_10bit(ADC_VOL, ADC_VREF_VCC)])); 
			}
			
			// FB Volume Pot ADC
			if(loop_counter==7) {
				//FBVR = PROGMEM_READ_BYTE(&(adc_to_wiper[adc_read_10bit(ADC_FBVOL, ADC_VREF_VCC)])); 
				FBVR = adc_read_8bit(ADC_FBVOL, ADC_VREF_VCC); 
			}
			
			// Encoder State Check(every 1msec Main Loop)
			switch(sample_encoder()) {
				case ENCODER_INCREMENT:
					if(!ioport_get_pin_level(SW0)) {
						switch(LCD_CMD) {
							case LCD_CMD_TRANSFER_REG:
								LCD_CMD = LCD_CMD_DISPLAY_SAVE;
							break;
							case LCD_CMD_DISPLAY_SAVE:
								LCD_CMD = LCD_CMD_DISPLAY_LOAD;
							break;
							case LCD_CMD_DISPLAY_LOAD:
								LCD_CMD = LCD_CMD_DISPLAY_VOLUME;
							break;
							case LCD_CMD_DISPLAY_VOLUME:
								LCD_CMD = LCD_CMD_TRANSFER_REG;
							break;
						}
					}
					else if((LCD_CMD==LCD_CMD_DISPLAY_LOAD)||(LCD_CMD==LCD_CMD_DISPLAY_SAVE)) {
						DCR1 = ((DCR1+(0x01<<MBANK0_BIT))&(get_bit_mask(MBANK0_BIT)|get_bit_mask(MBANK1_BIT)|get_bit_mask(MBANK2_BIT))) | (DCR1&~(get_bit_mask(MBANK0_BIT)|get_bit_mask(MBANK1_BIT)|get_bit_mask(MBANK2_BIT)));
					}
					else {
						switch(DCR1 & 0x01) {
							case DISPLAY_DELAY_TIME: 
								if(Get_Delay_Time_ms_to_Tempo(DTR, ((DCR2&(get_bit_mask(DTYPE2_BIT)|get_bit_mask(DTYPE1_BIT)|get_bit_mask(DTYPE0_BIT)))>>DTYPE0_BIT)) > (MIN_DELAY_TEMPO-1)) {
									switch(((DCR2&(get_bit_mask(DTYPE2_BIT)|get_bit_mask(DTYPE1_BIT)|get_bit_mask(DTYPE0_BIT)))>>DTYPE0_BIT)) {
										case 0: 
											if(DTR!=1000) DTR++;	// Transfer Gotten Delay Time to Tempo;
										break;
										case 1: 
											if(DTR!=750) DTR++;	// Transfer Gotten Delay Time to Tempo;
										break;
										case 2:
											if(DTR!=500) DTR++;	// Transfer Gotten Delay Time to Tempo;
										break;
										case 3: 
											if(DTR!=375) DTR++; // Transfer Gotten Delay Time to Tempo;
										break; 
										case 4:
											if(DTR!=333) DTR++;	// Transfer Gotten Delay Time to Tempo;
										break;
										case 5:
											if(DTR!=166) DTR++;	// Transfer Gotten Delay Time to Tempo;
										break;
									}
								}
								TPR = Get_Delay_Time_ms_to_Tempo(DTR, ((DCR2&(get_bit_mask(DTYPE2_BIT)|get_bit_mask(DTYPE1_BIT)|get_bit_mask(DTYPE0_BIT)))>>DTYPE0_BIT));	// Transfer Gotten Delay Time to Tempo
							break;
							case DISPLAY_TEMPO:
								if(TPR<MAX_DELAY_TEMPO) TPR++;
								DTR = Get_Tempo_to_Delay_Time_ms(TPR, ((DCR2&(get_bit_mask(DTYPE2_BIT)|get_bit_mask(DTYPE1_BIT)|get_bit_mask(DTYPE0_BIT)))>>DTYPE0_BIT));
							break;
							default:
							break;
						}
					}
					break;
				case ENCODER_DECREMENT: 
					if(!ioport_get_pin_level(SW0)) {
						switch(LCD_CMD) {
							case LCD_CMD_TRANSFER_REG:
							LCD_CMD = LCD_CMD_DISPLAY_VOLUME;
							break;
							case LCD_CMD_DISPLAY_VOLUME:
							LCD_CMD = LCD_CMD_DISPLAY_LOAD;
							break;
							case LCD_CMD_DISPLAY_LOAD:
							LCD_CMD = LCD_CMD_DISPLAY_SAVE;
							break;
							case LCD_CMD_DISPLAY_SAVE:
							LCD_CMD = LCD_CMD_TRANSFER_REG;
							break;
							default:
							break;
						}
					}
					else if((LCD_CMD==LCD_CMD_DISPLAY_LOAD)||(LCD_CMD==LCD_CMD_DISPLAY_SAVE)) {
						DCR1 = ((DCR1-(0x01<<MBANK0_BIT))&(get_bit_mask(MBANK0_BIT)|get_bit_mask(MBANK1_BIT)|get_bit_mask(MBANK2_BIT))) | (DCR1&~(get_bit_mask(MBANK0_BIT)|get_bit_mask(MBANK1_BIT)|get_bit_mask(MBANK2_BIT)));
					}
					else {
						switch(DCR1 & 0x01) {
							case DISPLAY_DELAY_TIME:
							if(Get_Delay_Time_ms_to_Tempo(DTR, ((DCR2&(get_bit_mask(DTYPE2_BIT)|get_bit_mask(DTYPE1_BIT)|get_bit_mask(DTYPE0_BIT)))>>DTYPE0_BIT)) < MAX_DELAY_TEMPO) {	// Transfer Gotten Delay Time to Tempo;
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

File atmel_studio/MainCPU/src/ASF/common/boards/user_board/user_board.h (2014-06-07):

/**
 * \file
 *
 * \brief User board definition template
 *
 */

 /* This file is intended to contain definitions and configuration details for
 * features and devices that are available on the board, e.g., frequency and
 * startup time for an external crystal, external memory devices, LED and USART
 * pins.
 */

#ifndef USER_BOARD_H
#define USER_BOARD_H

#include <conf_board.h>

// External oscillator settings.
// Uncomment and set correct values if external oscillator is used.

// External oscillator frequency
//#define BOARD_XOSC_HZ          8000000

// External oscillator type.
//!< External clock signal
//#define BOARD_XOSC_TYPE        XOSC_TYPE_EXTERNAL
//!< 32.768 kHz resonator on TOSC
//#define BOARD_XOSC_TYPE        XOSC_TYPE_32KHZ
//!< 0.4 to 16 MHz resonator on XTALS
//#define BOARD_XOSC_TYPE        XOSC_TYPE_XTAL

// External oscillator startup time
//#define BOARD_XOSC_STARTUP_US  500000

/* GPIO Connections
 * 
 */

#define PORT_DET	IOPORT_PORTA
#define INDET0		IOPORT_CREATE_PIN(PORTA, 1)
#define INDET1		IOPORT_CREATE_PIN(PORTA, 3)
#define OUTDET0		IOPORT_CREATE_PIN(PORTA, 4)
#define OUTDET1		IOPORT_CREATE_PIN(PORTA, 5)
#define SW0			IOPORT_CREATE_PIN(PORTA, 7)
#define SW1			IOPORT_CREATE_PIN(PORTA, 6)

#define CLK_N		IOPORT_CREATE_PIN(PORTB, 0)
#define CLK_P		IOPORT_CREATE_PIN(PORTB, 1)
#define PORT_ENC	IOPORT_PORTB
#define ENC_A		IOPORT_CREATE_PIN(PORTB, 2)
#define ENC_B		IOPORT_CREATE_PIN(PORTB, 3)
#define VOL			IOPORT_CREATE_PIN(PORTB, 4)
#define FBVOL		IOPORT_CREATE_PIN(PORTB, 5)
#define ON_OFF		IOPORT_CREATE_PIN(PORTB, 6)

#define ADC_VOL		ADC_MUX_ADC7
#define ADC_FBVOL	ADC_MUX_ADC8


/* GPIO Connections of I2S Bus
 * I2C Bus is connected to PORTA[2]/PORTA[0] and used as TWI function Port using USI. 
 * Sub CPU operate as I2S slave. 
 */
#define I2C			&USICR
#define SDA			IOPORT_CREATE_PIN(PORTA, 0)
#define SCL			IOPORT_CREATE_PIN(PORTA, 2)

#endif // USER_BOARD_H

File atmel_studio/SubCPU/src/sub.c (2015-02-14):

/**
 * \file
 *
 * \brief Empty user application template
 *
 */

/**
 * \mainpage User Application template doxygen documentation
 *
 * \par Empty user application template
 *
 * Bare minimum empty user application template
 *
 * \par Content
 *
 * -# Include the ASF header files (through asf.h)
 * -# Minimal main function that starts with a call to board_init()
 * -# "Insert application code here" comment
 *
 */

/*
 * Include header files for all drivers that have been imported from
 * Atmel Software Framework (ASF).
 */
#include <asf.h>
#include <stdlib.h>
#include <string.h>
#include "osslib/hd44780.h"
#include "osslib/xprintf.h"
#include "osslib/TWI_Slave.h"
#include "AnalogDelay.h"


// When there has been an error, this function is run and takes care of it
unsigned char TWI_Act_On_Failure_In_Last_Transmission ( unsigned char TWIerrorMsg );

void lcd_putstr(uint8_t *str) {

	uint8_t i = 0;

	while(*(str+i) != 0x00) {
		lcd_putc(*(str+i));
		i++;
	}

}

void set_custom_character() {
	// Custom Character Example
	uint8_t quarter_note_chr[8] = {0,4,4,4,4,28,28,0};				// Quarter note
	uint8_t dotted_quarter_note_chr[8] = {0,4,4,4,4,28,29,0};		// Dotted Quarter note
	uint8_t eighth_note_chr[8] = {0,6,7,5,4,28,28,0};				// Eighth note
	uint8_t dotted_eighth_note_chr[8] = {0,6,7,5,4,28,29,0};		// Dotted Eighth note
	uint8_t dotted_demiquaver_note_chr[8] = {12,14,11,12,14,11,24,25};		// Dotted demiquaver note
	uint8_t triplet_note_chr[8] = {8,8,8,11,25,27,1,3};				// Triplet
	uint8_t triplet_eighth_note_chr[8] = {12,14,8,11,25,27,1,3};				// Triplet eighth
					
	lcd_setcg(0x00, 1, (uint8_t*)quarter_note_chr);
	lcd_setcg(0x01, 1, (uint8_t*)dotted_eighth_note_chr);
	lcd_setcg(0x02, 1, (uint8_t*)eighth_note_chr);
	lcd_setcg(0x03, 1, (uint8_t*)dotted_demiquaver_note_chr);
	lcd_setcg(0x04, 1, (uint8_t*)triplet_note_chr);
	lcd_setcg(0x05, 1, (uint8_t*)triplet_eighth_note_chr);
	
}

void display_save(uint8_t DCR1) {
	
	irqflags_t flags;
	char STR[10] = {};
	uint8_t i;
	
	flags = cpu_irq_save();
	lcd_locate(0, 0);
	lcd_putstr("SAVE    ");
	lcd_locate(1, 0);
	lcd_putstr("   ");
	lcd_putc(0x7E);
	lcd_putstr("MEM");
	i = (DCR1&(get_bit_mask(MBANK0_BIT)|get_bit_mask(MBANK1_BIT)|get_bit_mask(MBANK2_BIT)))>>MBANK0_BIT;
	itoa(i, STR, 10);
	lcd_putstr(STR);

	cpu_irq_restore(flags);
	
}

void display_load(uint8_t DCR1) {
	
	irqflags_t flags;
	char STR[10] = {};
	uint8_t i, j;
	
	flags = cpu_irq_save();
	lcd_locate(0, 0);
	lcd_putstr("LOAD    ");
	lcd_locate(1, 0);
	lcd_putstr("   ");
	lcd_putc(0x7F);
	lcd_putstr("MEM");
	i = (DCR1&(get_bit_mask(MBANK0_BIT)|get_bit_mask(MBANK1_BIT)|get_bit_mask(MBANK2_BIT)))>>MBANK0_BIT;
	itoa(i, STR, 10);
	lcd_putstr(STR);

	cpu_irq_restore(flags);
	
}

void display_volume(uint8_t VOLR, uint8_t FBVR) {
	
	irqflags_t flags;
	char STR[10] = {};
	uint8_t i, j;
	
	flags = cpu_irq_save();
	lcd_locate(0, 0);
	lcd_putstr("VOL: ");
	itoa(VOLR, STR, 10);
	j = strlen(STR);
	for(i=3; i>j; i--) {
		lcd_putc(0x20);
	}
	lcd_putstr(STR);
	
	lcd_putstr("FB : ");
	itoa(FBVR, STR, 10);
	j = strlen(STR);
	for(i=3; i>j; i--) {
		lcd_putc(0x20);
	}
	lcd_putstr(STR);

	cpu_irq_restore(flags);
	
}
	
void display_status(uint8_t DCR0, uint8_t DCR1, uint16_t DTR, uint16_t TPR, uint8_t DCR2) {
	
	irqflags_t flags;
	char DTR_STR[10] = {};
	char TPR_STR[10] = {};
	uint8_t i, j;
	
	flags = cpu_irq_save();
	
	lcd_locate(0,0); 
	if(DCR0 & get_bit_mask(ON_OFF_BIT)) {
		if((DCR0 & (get_bit_mask(INDET1_BIT) | get_bit_mask(INDET0_BIT))) \
		== (get_bit_mask(INDET1_BIT) | get_bit_mask(INDET0_BIT))) {
			lcd_putstr("S.DELAY");
		}
		else {
			lcd_putstr("DELAY  ");
		}
	}
	else if(DCR0 & get_bit_mask(INDET1_BIT)) {
		if(((DCR0 & (get_bit_mask(OUTDET1_BIT) | get_bit_mask(OUTDET0_BIT))) == (get_bit_mask(OUTDET1_BIT))) \
		|| ((DCR0 & (get_bit_mask(OUTDET1_BIT) | get_bit_mask(OUTDET0_BIT))) == (get_bit_mask(OUTDET0_BIT)))) {
			lcd_putstr("BYPASS ");
		}
		else if((DCR0 & (get_bit_mask(OUTDET1_BIT) | get_bit_mask(OUTDET0_BIT) | get_bit_mask(DRY_MIX_BIT))) \
		== ((get_bit_mask(OUTDET1_BIT) | get_bit_mask(OUTDET0_BIT)))) {
			lcd_putstr("BYPASS ");
		}
		else {
			lcd_putstr("FXOFF  ");
		}
	} 
	else {
		lcd_putstr("FXOFF  ");
	}
	lcd_locate(0, 7);
	switch(DCR2&0x07) {		// Tempo mode Display switch
		case 0:
			lcd_putc(0x00);
		break;
		case 1:
			lcd_putc(0x01);
		break;
		case 2:
			lcd_putc(0x02);
		break;
		case 3:
			lcd_putc(0x03);
		break;
		case 4: 
			lcd_putc(0x04);
		break; 
		case 5:
			lcd_putc(0x05);
		break;
		default:
		break;
	}
	lcd_locate(1, 0);
	if((DCR0 & (get_bit_mask(INDET1_BIT) | get_bit_mask(INDET0_BIT))) && (DCR0 & (get_bit_mask(OUTDET1_BIT) | get_bit_mask(OUTDET0_BIT)))) {
		if(DCR1 & get_bit_mask(BSN_BIT)) {
			if((DCR0 & (get_bit_mask(INDET1_BIT) | get_bit_mask(INDET0_BIT) | \
			get_bit_mask(OUTDET1_BIT) | get_bit_mask(OUTDET0_BIT) | get_bit_mask(ON_OFF_BIT))) \
			== (get_bit_mask(INDET1_BIT) | get_bit_mask(OUTDET0_BIT))) {
				lcd_putstr(" ");
			}
			else {
				lcd_putstr("L");
			}
		}
		else {
			if((DCR0 & (get_bit_mask(INDET1_BIT) | get_bit_mask(INDET0_BIT) | \
			get_bit_mask(OUTDET1_BIT) | get_bit_mask(OUTDET0_BIT) | get_bit_mask(ON_OFF_BIT))) \
			== (get_bit_mask(INDET1_BIT) | get_bit_mask(OUTDET1_BIT))) {
				lcd_putstr(" ");
			}
			else if((DCR0 & (get_bit_mask(INDET1_BIT) | get_bit_mask(INDET0_BIT) | \
			get_bit_mask(OUTDET1_BIT) | get_bit_mask(OUTDET0_BIT) | get_bit_mask(ON_OFF_BIT) | get_bit_mask(DRY_MIX_BIT))) \
			== (get_bit_mask(INDET1_BIT) | get_bit_mask(OUTDET1_BIT) | get_bit_mask(OUTDET0_BIT))) {
				lcd_putstr(" ");
			}
			else if((DCR0 & (get_bit_mask(INDET1_BIT) | get_bit_mask(INDET0_BIT) | \
			get_bit_mask(OUTDET1_BIT) | get_bit_mask(OUTDET0_BIT) | get_bit_mask(DRY_MIX_BIT))) \
			== (get_bit_mask(INDET0_BIT) | get_bit_mask(OUTDET1_BIT) | get_bit_mask(OUTDET0_BIT))) {
				lcd_putstr("S");
			}
			else if((DCR0 & (get_bit_mask(INDET1_BIT) | get_bit_mask(INDET0_BIT) | \
			get_bit_mask(OUTDET1_BIT) | get_bit_mask(OUTDET0_BIT) | get_bit_mask(ON_OFF_BIT) |get_bit_mask(DRY_MIX_BIT))) \
			== (get_bit_mask(INDET1_BIT) | get_bit_mask(OUTDET1_BIT) | get_bit_mask(OUTDET0_BIT) | get_bit_mask(ON_OFF_BIT))) {
				lcd_putstr("S");
			}
			else {
				lcd_putstr("S");
			}
		}
	}
	else {
		lcd_putstr(" ");
	}
	if((DCR0 & (get_bit_mask(DRY_MIX_BIT) | get_bit_mask(OUTDET1_BIT) | get_bit_mask(OUTDET0_BIT))) \
	== (get_bit_mask(DRY_MIX_BIT) | get_bit_mask(OUTDET1_BIT) | get_bit_mask(OUTDET0_BIT))) {
			lcd_putstr("D");
	}
	else if((DCR0 & (get_bit_mask(INDET1_BIT) | get_bit_mask(INDET0_BIT) | \
	get_bit_mask(OUTDET1_BIT) | get_bit_mask(OUTDET0_BIT) | get_bit_mask(DRY_MIX_BIT))) \
	== (get_bit_mask(INDET0_BIT) | get_bit_mask(OUTDET1_BIT) | get_bit_mask(OUTDET0_BIT))) {
		lcd_putstr("P");
	}
	else if((DCR0 & (get_bit_mask(INDET1_BIT) | get_bit_mask(INDET0_BIT) | \
	get_bit_mask(OUTDET1_BIT) | get_bit_mask(OUTDET0_BIT) | get_bit_mask(ON_OFF_BIT) |get_bit_mask(DRY_MIX_BIT))) \
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

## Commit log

2014-06-07 1st Commit
    [AnalogAmbient_Doc.ods, AnalogDelay-sub.kicad_pcb, AnalogDelay-sub.sch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]
2014-06-07 Add: Library cache.lib(kicad)
2014-06-07 Add: compander sch&pcb mod: constants
    [AnalogDelay.sch, BBD_Block.sch, Connect_Block.sch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]
2014-06-15 mod: Schematics
    [AnalogDelay.sch, BBD_Block.sch, Connect_Block.sch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]
2014-06-15 Fix: IN2 NOT Enable
    [AnalogAmbient_Doc.ods]
2015-02-14 Mod: Delay Mode Type(Add dotted sixteen note, triplet eighth mode, remove dotted quarter note). Mod: Delay Mode Icons.
    [AnalogAmbient_Doc.ods]
